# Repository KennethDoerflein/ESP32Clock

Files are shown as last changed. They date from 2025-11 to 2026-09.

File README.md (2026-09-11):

# ESP32-S3 WiFi Clock

This repository contains the firmware for a feature-rich, Wi-Fi connected smart clock powered by an ESP32-S3 microcontroller. It features a large 4" color IPS display, a web-based interface for easy configuration, automatic time synchronization, environmental sensing, and detailed weather forecasts.

## Table of Contents

- [Features](#features)
- [Hardware Requirements](#hardware-requirements)
- [Assembly](#assembly)
- [Wiring](#wiring)
- [Software Setup](#software-setup)
- [Software Architecture](#software-architecture)
- [Usage Guide](#usage-guide)
  - [First-Time Setup](#first-time-setup)
  - [Web Interface](#web-interface)
  - [Physical Button Functions](#physical-button-functions)
  - [Safe Mode & Boot Loop Protection](#safe-mode--boot-loop-protection)
  - [Factory Reset](#factory-reset)
- [Features and Settings in Detail](#features-and-settings-in-detail)
  - [WiFi Page](#wifi-page)
  - [Alarms Page](#alarms-page)
  - [Weather Page](#weather-page)
  - [Settings Page](#settings-page)
  - [Logs Page](#logs-page)
  - [System Page](#system-page)
  - [Temperature & Environmental Sensor Architecture](#temperature--environmental-sensor-architecture)
- [Project Roadmap](#project-roadmap)

## Features

- **Large Color Display**: A 4" 480x320 color IPS display provides a clear and vibrant user interface with smooth anti-aliased font rendering and sprite-based double buffering.
- **Rich Weather Forecasts**: Local weather powered by the Open-Meteo API, including current temperature, apparent "feels like" temperature, relative humidity, wind speed, wind direction, wind gusts, rain probability, cloud cover, UV index, atmospheric pressure, visibility, weather conditions, and daily sunrise/sunset times.
- **Asynchronous Geocoding**: Enter any city or address (e.g., "New York, NY" or "Paris, France") and coordinates are automatically resolved asynchronously via the Open-Meteo Geocoding API with state-code awareness.
- **Multi-Layer Timekeeping & Synchronization**:
  - Hardware DS3231 Real-Time Clock with battery backup ensures uninterrupted timekeeping across power outages.
  - Multi-tier NTP synchronization (primary: `time.nist.gov`, backup: `time.cloudflare.com`, fallback: `us.pool.ntp.org`) with exponential backoff and jitter.
  - Daily automatic synchronization, periodic drift detection and resyncing.
  - Initial boot seeding from RTC to guarantee accurate timestamps prior to network connection.
  - Browser-to-device one-click manual time sync via web interface for air-gapped or offline setups.
  - Automatic Daylight Saving Time (DST) detection and full POSIX timezone support.
- **Advanced Dynamic Alarms**:
  - Configure up to 20 alarms via the web interface.
  - Set custom hour and minute, individual days of the week, or one-time alarms.
  - **Biweekly Scheduling**: Configure alarms to repeat every other week (even or odd week cycles).
  - **3-Stage Progressive Ramping Buzzer**: Transitions from slow beeping (10s) to rapid beeping (20s) to continuous tone.
  - Visual alarm indicators: flashing display backlight and on-screen active alarm / snooze countdown overlay.
  - **Reboot Persistence & Auto-Shutoff**: Automatically resumes ringing if a power cycle occurs while active, and automatically silences after 30 minutes.
  - **Missed Alarm Catch-Up**: Detects and triggers alarms that were missed during unexpected power outages or clock adjustments (capped at 90 minutes).
  - Customizable snooze duration and hold-to-dismiss timer.
- **Environmental Sensing & Thermal Compensation**:
  - BME280 sensor reads ambient room temperature, relative humidity, and pressure with fallback to DS3231 internal sensor.
  - Exponential moving average (EMA) noise filtering.
  - Cold-boot automatic temperature calibration.
  - Configurable enclosure heat compensation factor and manual offset correction.
  - Relative humidity compensation based on the August-Roche-Magnus approximation.
- **Multi-Page Display Management**:
  - 4 built-in display pages: **Clock**, **Weather**, **Weather+Clock** (combined), and **Info**.
  - Enable, disable, and custom-order pages via Move Up / Move Down buttons in the web interface.
  - Configurable startup/default page.
  - Physical button single-press page cycling with display preemption on Core 1 for stutter-free rendering.
- **Customizable Appearance**:
  - Full hex color picker support for individual UI elements: Background, Time, AM/PM, Seconds, Day of Week, Date, Temperature, Humidity, Alarm/Snooze icons, Weather Temp, and Forecast conditions.
  - Screen flip (180° rotation) and color inversion toggles.
  - 12-hour (with AM/PM) or 24-hour format; Fahrenheit or Celsius temperature units.
- **Smart Backlight Control**:
  - Scheduled Auto Brightness with custom day/night transition hours and brightness levels.
  - Manual brightness slider (0–255 PWM).
- **Offline Mode**: Complete disconnected operation with WiFi and online polling turned off.
- **WiFi Connectivity & Captive Portal**:
  - Connects to 2.4 GHz 802.11 b/g/n networks.
  - Automatic Access Point (`Clock-Setup`) and Captive Portal with OS connectivity detection if unconfigured or connection fails.
  - In-browser network scanning and non-blocking credential testing.
  - Custom hostname and mDNS address (e.g., `http://ESP32Clock-XXXXXX.local`).
- **Secure OTA Updates**:
  - Over-the-Air firmware updates directly from the web interface.
  - GitHub Releases integration: one-click check and update directly from GitHub repository releases. This method uses Ed25519 signature verification to prevent unauthorized firmware installations.
  - Manual web uploads are unverified and intended for sideloading/development.
  - Dual-OTA partition layout (`app0` / `app1`) with automatic rollback on boot failure.
- **Diagnostics, Crash Recovery & Safe Mode**:
  - Boot loop detection: enters a minimal recovery environment (`Clock-SafeMode`) after repeated crash-boots.
  - Hardware Task Watchdog Timer (TWDT) monitoring critical FreeRTOS tasks.
  - RTC-backed crash log capturing panic and exception traces across unexpected reboots.
  - Core dump support stored in a dedicated flash partition (`coredump.bin`) with web download and erase tools.
  - Real-time WebSocket live logging and persistent rotating log files (`system.log`).
- **Hardware & Web Factory Reset**: Multiple reset mechanisms (Web UI, runtime BOOT button 10s hold, or power-on Snooze button hold) with options to keep or clear WiFi credentials. LittleFS is formatted during factory reset, wiping system logs so the device is like brand new.

## Hardware Requirements

| Component | Description |
| --- | --- |
| **Microcontroller** | **ESP32-S3-WROOM-1 N16R8** Development Board (16MB Flash, 8MB PSRAM) |
| **Display** | **4" ILI9488 IPS LCD** Display Module (480x320) with SPI interface |
| **Real-Time Clock** | **DS3231** RTC Module with a LIR2032 battery for backup |
| **Sensor** | **BME280** Temperature, Humidity, and Pressure Sensor Module (I2C) |
| **Power Supply** | A reliable 5V USB-C power supply |

## Case 3D Model

[Download](./case%20model/ESP32%20Clock%20Case%204%20inch%20v18.step)

## Parts List

Here is a list of all the components required to build the ESP32-S3 WiFi Clock, along with purchase links:

| Component | Description | Link |
| --- | --- | --- |
| **ESP32-S3-WROOM-1 Development Board** | 16MB Flash, 8MB PSRAM | [AliExpress Link](https://a.aliexpress.com/_mMm2jWD) |
| **4" ILI9488 IPS LCD Display** | 480×320 SPI interface | [AliExpress Link](https://a.aliexpress.com/_mt2vtEh) |
| **DS3231 RTC Module** | With LIR2032 battery backup | [AliExpress Link](https://a.aliexpress.com/_mPeDmLR) |
| **BME280 Sensor Module** | Temperature, Humidity, Pressure, I2C | [AliExpress Link](https://a.aliexpress.com/_mtACD9f) |
| **Active Buzzer** | Any small 5V buzzer | [AliExpress Link](https://a.aliexpress.com/_mKjibtR) |
| **6x6x7.2mm Micro Switch** | For Snooze/Stop functionality | can source locally |
| **USB-C Inlet** | For powering the clock | [AliExpress Link](https://a.aliexpress.com/_msBRQoD) |
| **5V USB-C Power Supply** | Reliable 5V power source | can source locally |
| **Male Machine Pin Headers** | For connecting modules to boards | [AliExpress Link](https://a.aliexpress.com/_mPmIdmp) |
| **DuPont Wires (Male-to-Male / Female-to-Male / Female-to-Female)** | For connections between headers | [AliExpress Link](https://a.aliexpress.com/_mLxGsFP) |
| **DuPont Wire Kit (Headers + Housing)** | 310 pcs set for custom connections | [AliExpress Link](https://a.aliexpress.com/_msXyJap) |
| **Prototype Boards / Perfboards** | For mounting modules | can source locally |
| **Heat-Set Inserts** | For case assembly | can source locally |
| **Screws (M2)** | For case and module mounting | [AliExpress Link](https://a.aliexpress.com/_mtl7Jwt) |

## Assembly

Follow these steps to assemble the ESP32-S3 WiFi Clock:

1. **Flash Firmware**  
   Flash the initial firmware to the ESP32-S3 before starting physical assembly.

2. **Prepare Headers**

   - Replace the existing headers on the display and RTC modules with male machine pin headers.
   - Solder a male dupont header onto the BME280 sensor.

3. **Connect Display**

   - Solder the display header to the prototype board.
   - Route the wires carefully to the opposite side for easy access.  
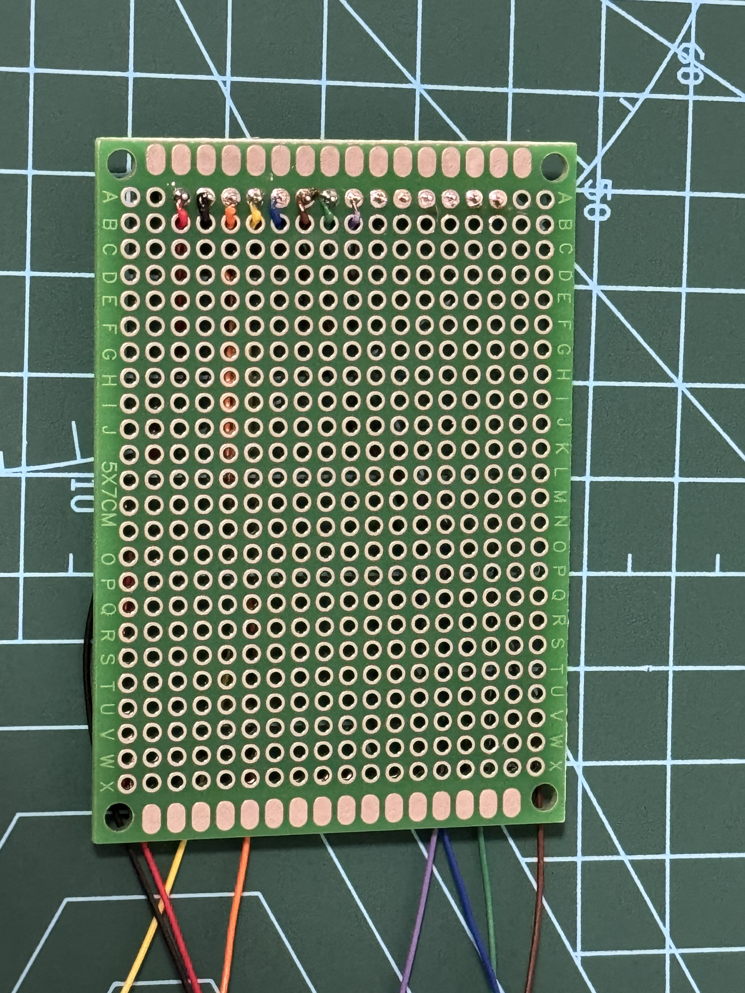
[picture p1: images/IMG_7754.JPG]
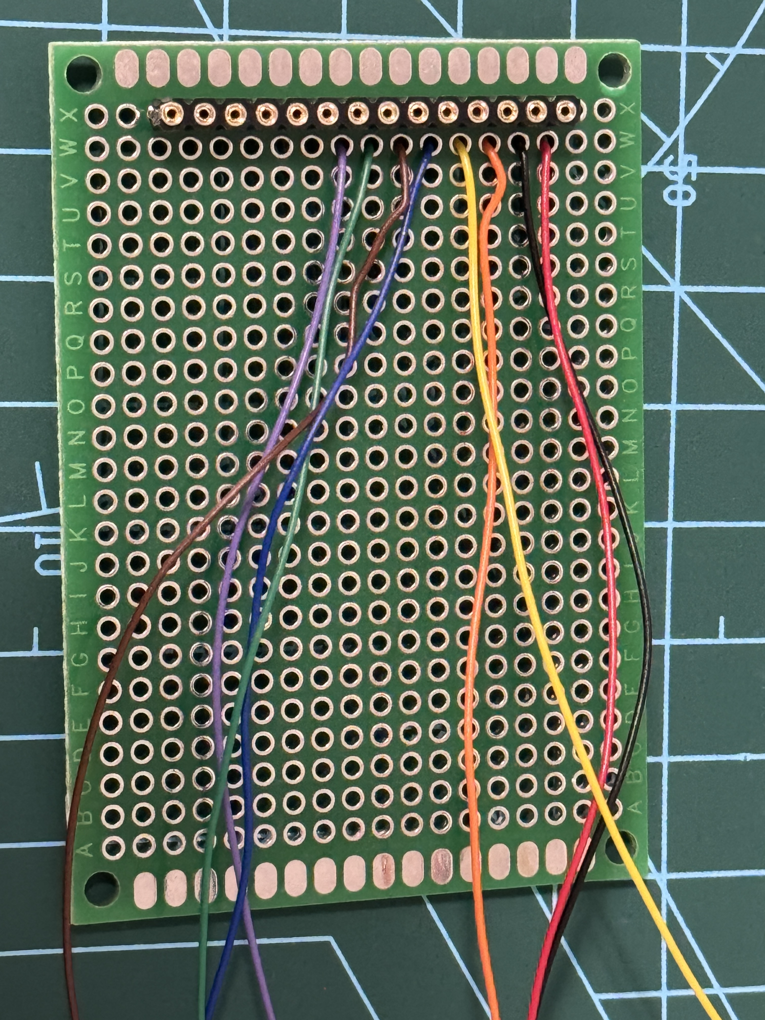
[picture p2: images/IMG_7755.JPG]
      

4. **Solder Remaining Headers**

   - Connect all other headers and wires.
   - Keep wires slightly longer in case adjustments are needed.  
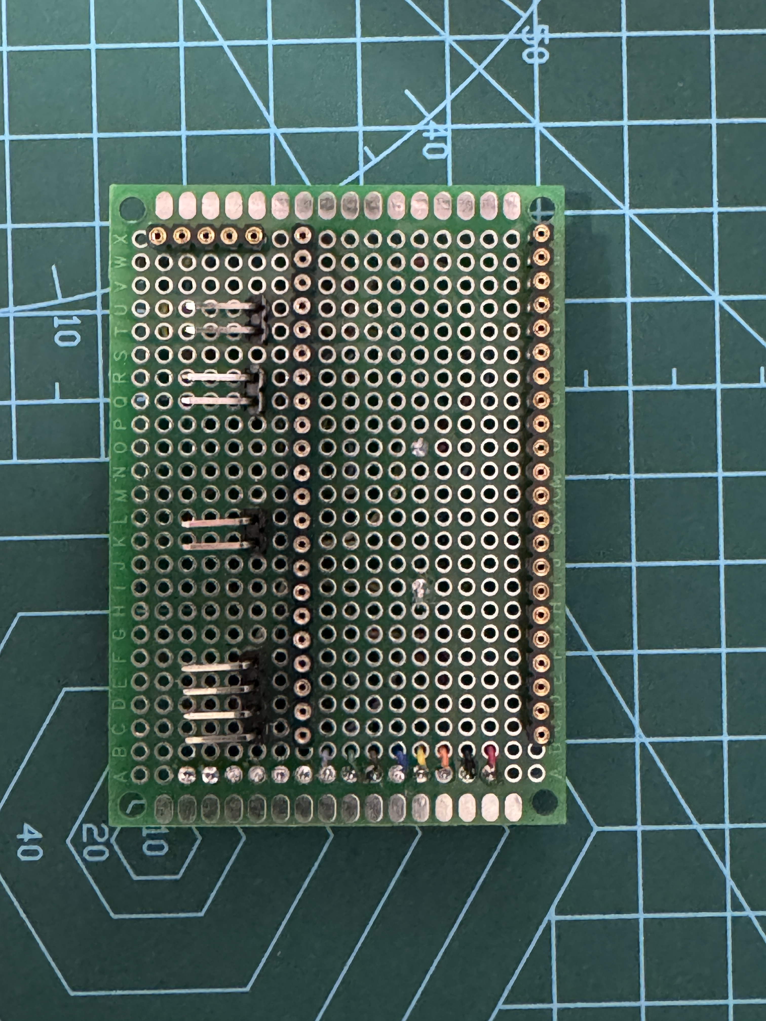
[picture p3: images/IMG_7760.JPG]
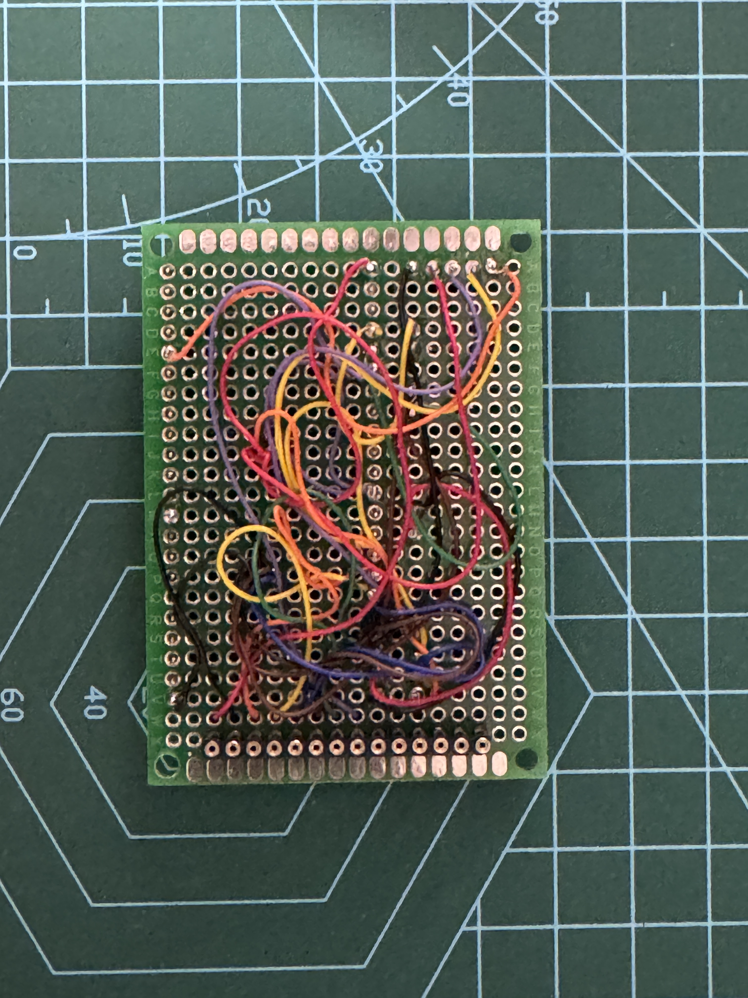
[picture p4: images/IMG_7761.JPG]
      

5. **Fit Components**

   - Ensure the modules fit inside the case.
   - Sand the sides of the RTC if space is tight.  
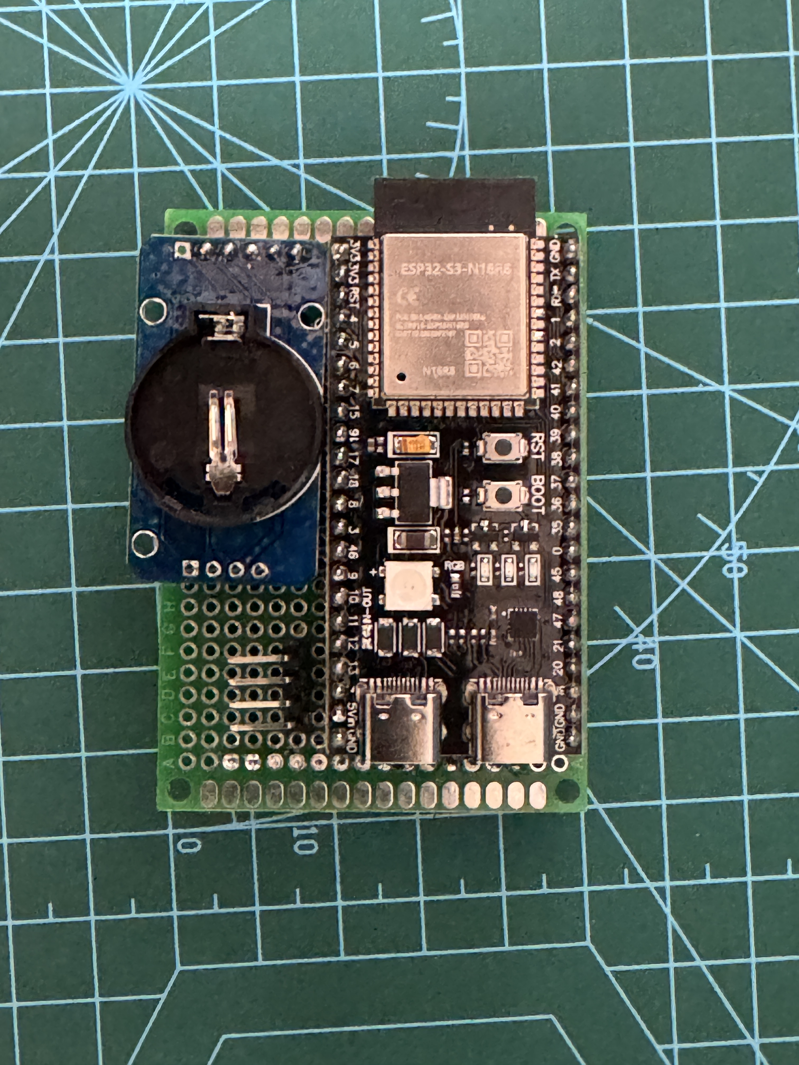
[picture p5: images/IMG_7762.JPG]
     

6. **Install Heat-Set Inserts**

   - Insert into the back panel of the case for M2 screws (sizes: 3×3.2mm and 2×4mm).  
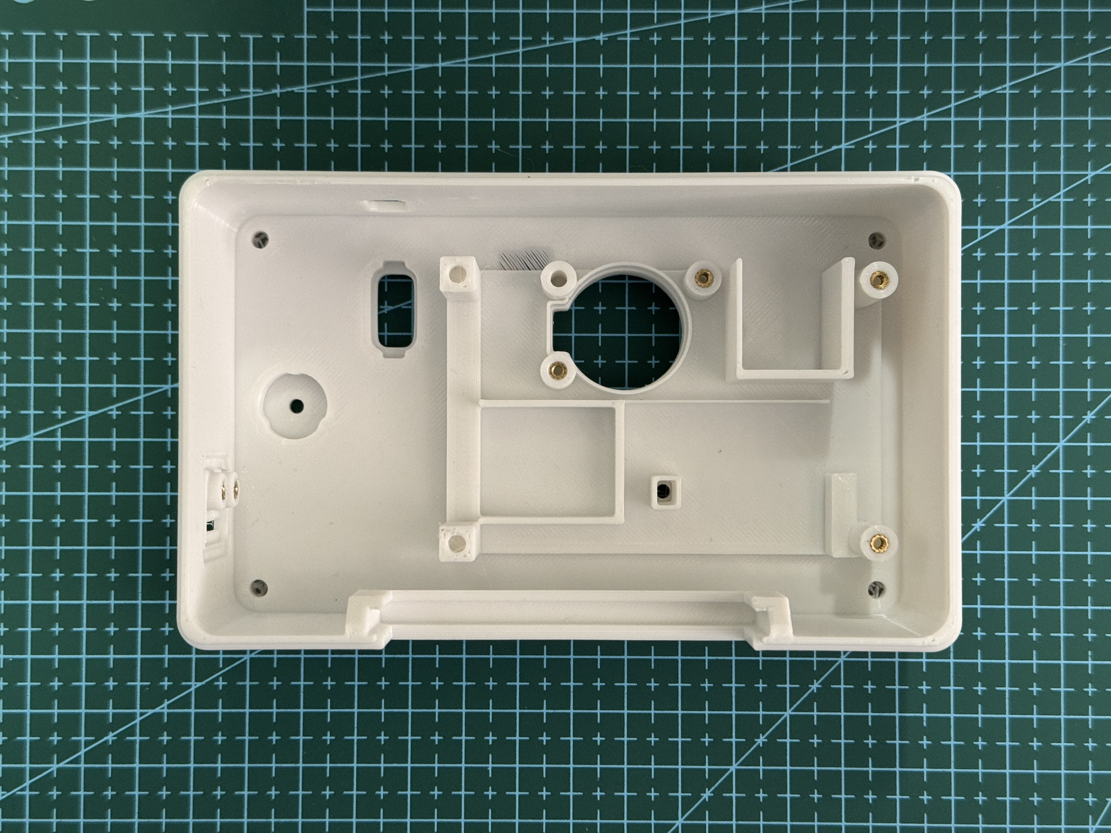
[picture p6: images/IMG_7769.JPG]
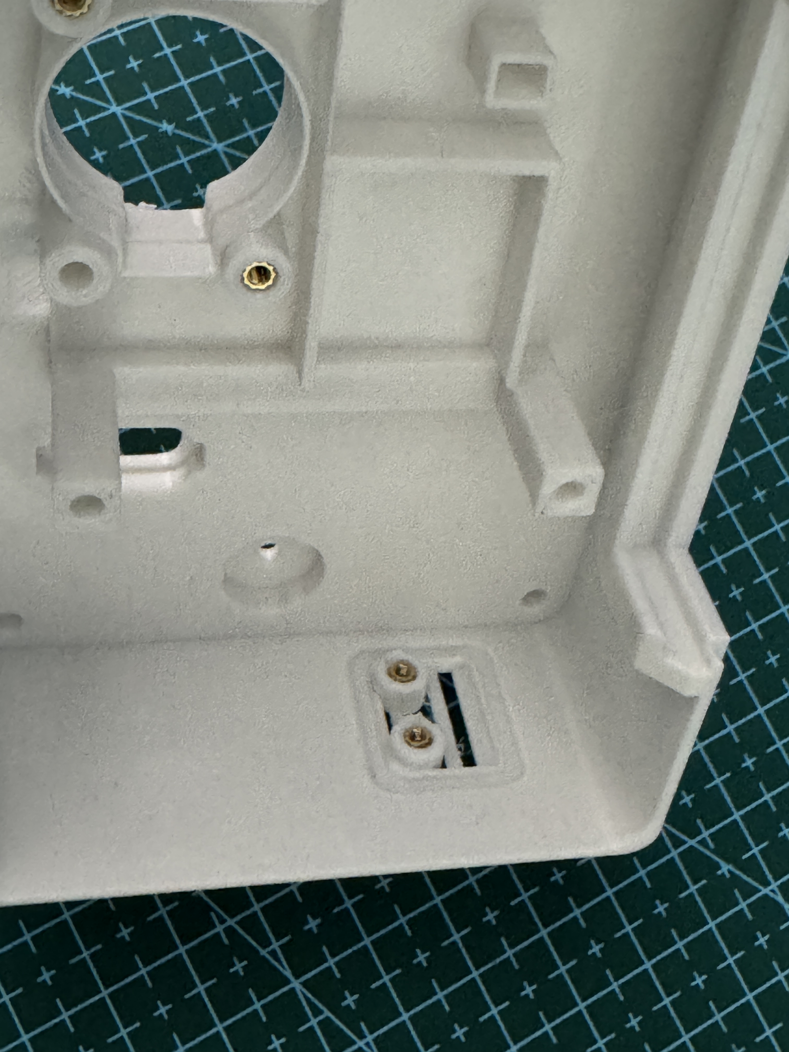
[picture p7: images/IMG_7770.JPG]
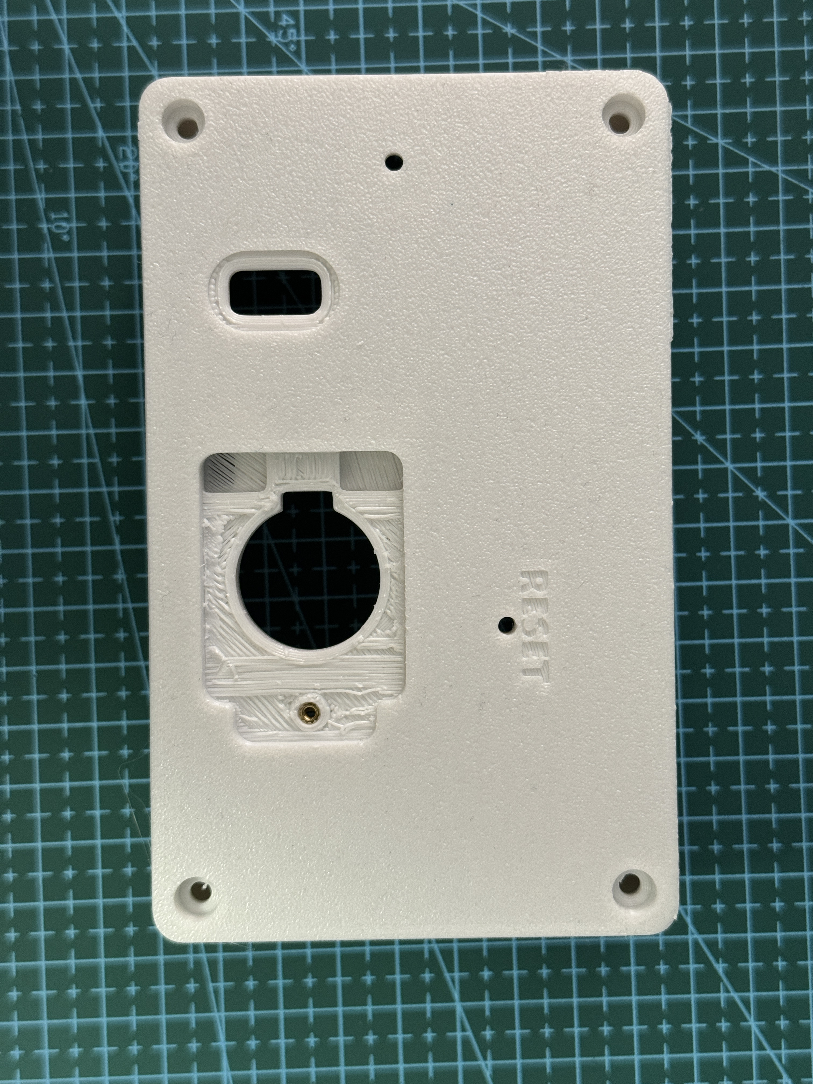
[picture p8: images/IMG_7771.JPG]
       

7. **Install Front Panel Inserts**

   - Install inserts for the display (M2) and posts (M3).

8. **Assemble Components**

   - Plug in all connectors.
   - Secure the display, RTC, and sensors with the appropriate screws.  
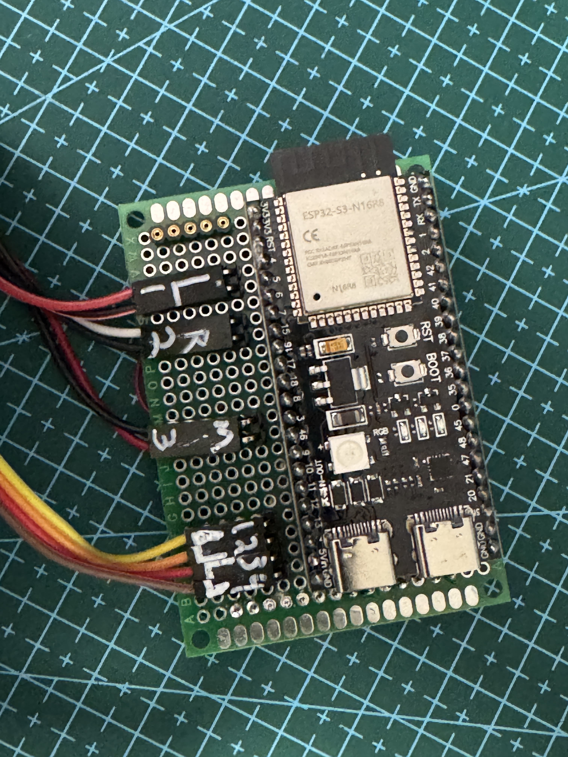
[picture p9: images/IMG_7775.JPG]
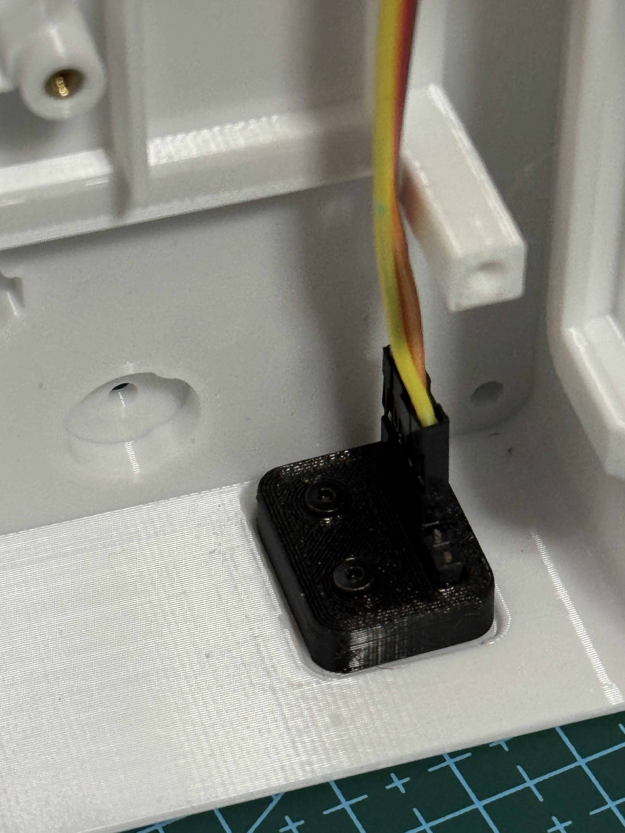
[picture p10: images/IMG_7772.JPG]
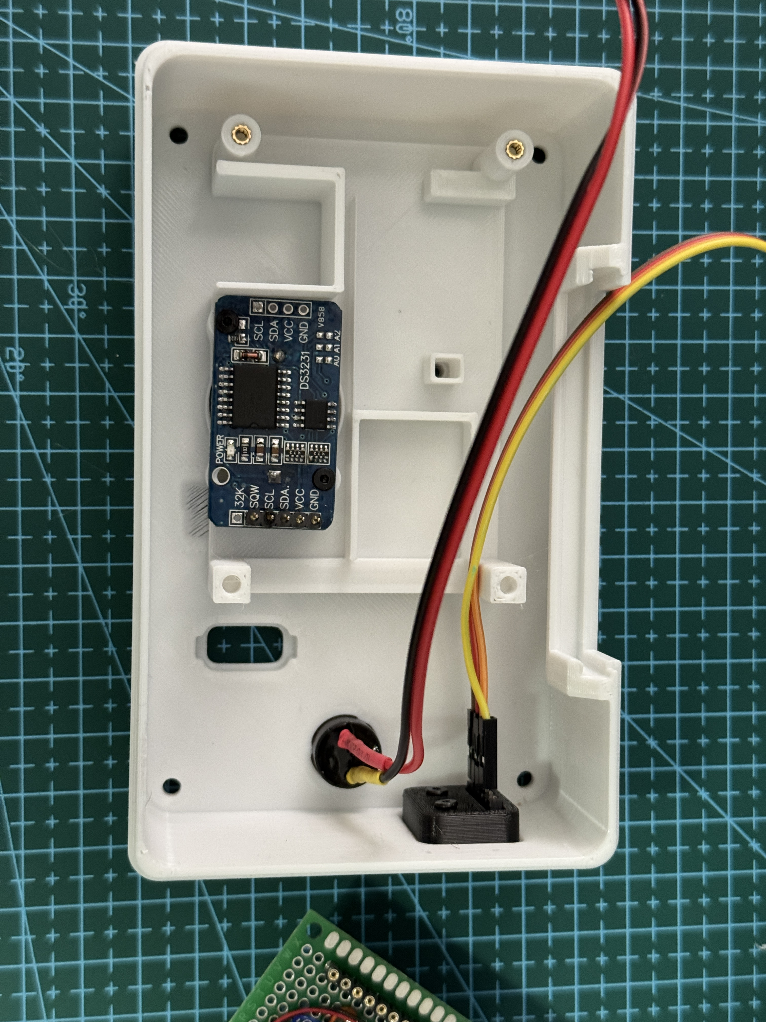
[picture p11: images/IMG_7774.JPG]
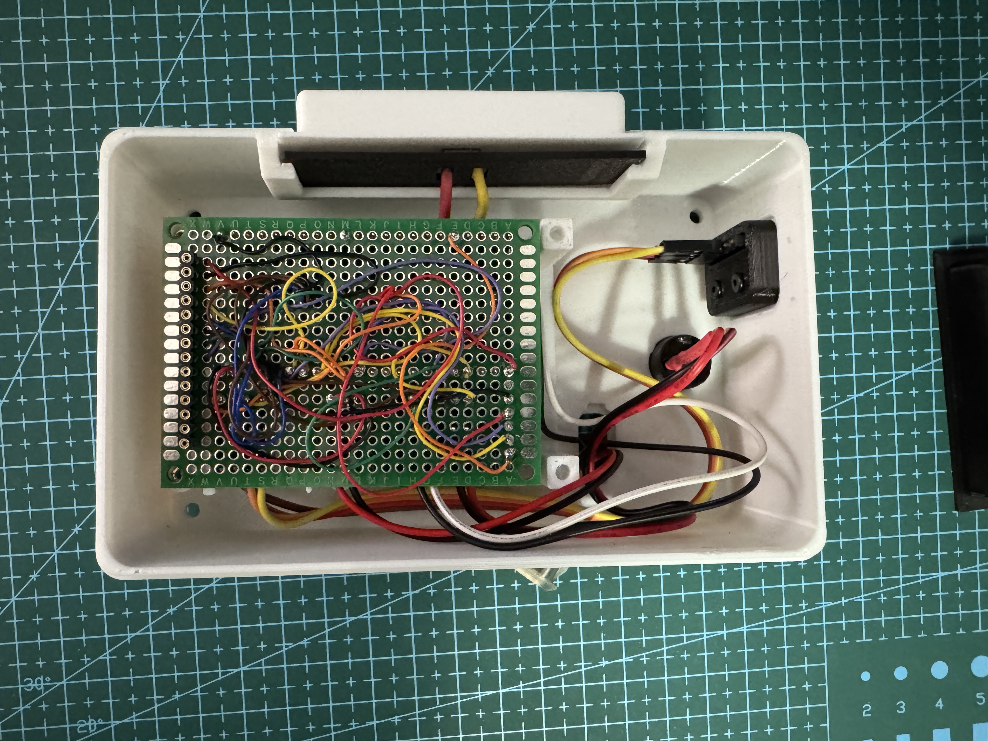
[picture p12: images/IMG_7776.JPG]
        

9. **Close Case and Power On**
   - Screw the case together and connect power.  
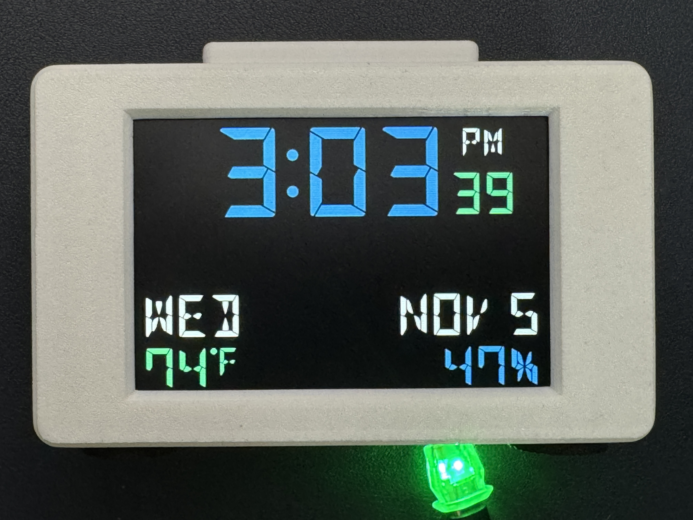
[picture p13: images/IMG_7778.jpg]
     

## Wiring

The components are connected using the I2C and SPI buses.

| Component | Pin | ESP32-S3 GPIO | Notes |
| --- | --- | --- | --- |
| **4" ILI9488 IPS (SPI)**  | VCC | 3.3V | Connect to 3.3V pin |
| | GND | GND | Common ground |
| | CS | GPIO 10 | Chip Select |
| | RST | GPIO 11 | Reset |
| | DC | GPIO 12 | Data/Command |
| | MOSI | GPIO 13 | Data In |
| | SCK | GPIO 14 | Clock |
| | LED | GPIO 6 | Backlight (PWM) |
| | MISO | UNUSED | Data Out |
| **DS3231 & BME280 (I2C)** | VCC | 3.3V | Shared 3.3V |
| | GND | GND | Shared ground |
| | SDA | GPIO 8 | Shared data line |
| | SCL | GPIO 9 | Shared clock line |
| DS3231 | SQW | GPIO 2 | Interrupt for alarms  |
| **Active Buzzer** | + | GPIO 4 | Any free GPIO |
| | - | GND | Common ground |
| **Stop/Snooze Button** | One leg | GPIO 5 | Use INPUT_PULLUP mode |
| | Other leg | GND | Common ground |

## Software Setup

This project is developed using **PlatformIO**.

### Libraries

The following libraries are required and are automatically managed by PlatformIO via the `platformio.ini` file:

- `bodmer/TFT_eSPI`
- `bblanchon/ArduinoJson`
- `adafruit/RTClib`
- `adafruit/Adafruit BME280 Library`
- `esphome/ESPAsyncWebServer-esphome`
- `esphome/AsyncTCP-esphom`

### Build Instructions

1.  **Clone the Repository**:
    ```bash
    git clone https://github.com/KennethDoerflein/ESP32Clock.git
    cd ESP32Clock
    ```
2.  **Open in PlatformIO**: Open the project folder in VS Code with the PlatformIO extension installed.
3.  **Build & Upload**: Use the PlatformIO "Build" and "Upload" commands to compile and flash the firmware to your ESP32-S3.

---

## Software Architecture

The firmware is organized into a collection of singleton manager classes and modular components running across the ESP32-S3's dual cores (Core 0 for network/logic/logging; Core 1 for display rendering and timekeeping):

- **`AlarmManager`**: Manages physical alarm ringing, buzzer frequency ramping across 3 progressive stages (slow beep -> fast beep -> continuous), display backlight flashing, reboot resume, and auto-shutoff timer.
- **`ButtonManager`**: Provides debounced interrupt-based input handling for the multi-function physical button (press durations, page switching, snooze, and hold-to-dismiss).
- **`ClockWebServer`**: Asynchronous web server hosting the configuration UI, REST API endpoints, live log WebSocket server, captive portal, and firmware upload receiver.
- **`ConfigManager`**: Thread-safe configuration manager utilizing ESP32 NVS Preferences for persistent storage with write debouncing to protect flash memory.
- **`DisplayManager`**: Orchestrates active display page lifecycle, page transitions, alarm overlay banners, dismiss progress bars, and status icons with display preemption on Core 1 for zero jitter.
- **`Display`**: Low-level TFT display abstraction (ILI9488 SPI driver), screen rotation, color inversion, and LEDC PWM backlight control.
- **`FirmwareVerifier`**: Provides cryptographic verification using Ed25519 signatures and SHA-256 streaming hashing before applying firmware updates.
- **`NtpSync`**: Multi-tiered NTP client featuring exponential backoff, jitter, and automatic fallback across NIST, Cloudflare, and NTP Pool servers.
- **`SensorModule`**: Interfaces with the BME280 (I2C) and DS3231 sensors, implementing I2C bus recovery, exponential moving average (EMA) noise filtering, enclosure thermal compensation, and August-Roche-Magnus humidity correction.
- **`SerialLog`**: Centralized thread-safe logger mirroring serial output to a live WebSocket feed, persistent rotating LittleFS file (`system.log`), and RTC memory crash dump buffer.
- **`TimeManager`**: High-accuracy timekeeping coordinator bridging the DS3231 hardware RTC and ESP32 system clock, tracking Daylight Saving Time, drift compensation, missed alarm detection, and biweekly parity calculations.
- **`UpdateManager`**: Handles OTA firmware updates via file upload and automated GitHub Releases checks with cryptographic signature verification and dual-OTA partition rollback safety.
- **`WeatherService`**: Handles asynchronous geocoding and fetches comprehensive weather metrics from Open-Meteo via HTTPS with PSRAM-backed JSON filtering; network loops execute in the background Logic Task (Core 0) with HTTPS requests offloaded to a persistent FreeRTOS worker (`WeatherUpdate` on Core 1 at priority 1, preempted by Core 1 display rendering).
- **`WiFiManager`**: Manages WiFi STA connection, automatic reconnection, non-blocking connection tests, DNS captive portal, network scanning, and mDNS responder.
- **`Page`**: An abstract base class for display pages:
  - **`ClockPage`**: Large retro-styled digital clock face with time, AM/PM, seconds, day of week, date, indoor temperature, indoor humidity, and next alarm indicators.
  - **`WeatherPage`**: Dedicated weather display showing current outdoor temperature, condition description, humidity, wind, and rain chance.
  - **`WeatherClockPage`**: Split-layout screen combining clock display with live outdoor conditions and indoor environmental data.
  - **`InfoPage`**: Static information screen showing device hostname, IP address, and firmware version.

---

## Usage Guide

### First-Time Setup

1.  On the first boot, or if WiFi credentials are not configured/valid, the clock will start a Wi-Fi Access Point (AP). The SSID will be **`Clock-Setup`**.
2.  Connect to this network from your phone or computer.
3.  Open a web browser and navigate to the clock's static IP address, which is **`http://192.168.4.1`**. This address is fixed when the clock is in AP mode.

### Web Interface

The web interface provides access to all the clock's settings. Once connected to your WiFi network, you can access the web interface by navigating to the IP address shown on the clock's display or by using its mDNS address (e.g., `http://ESP32Clock-XXXXXX.local`).

The web interface is organized into several sections:

- **Configure WiFi**: For connecting to your local network and setting a hostname.
- **Alarms**: For setting and managing up to 20 alarms.
- **Weather**: For configuring the location and viewing weather status.
- **Settings**: For adjusting display, time, brightness, and page configuration.
- **Logs**: For viewing live logs and managing log files.
- **System**: For system-level actions like updates, reboots, and viewing system information.

### Physical Button Functions

The physical button (connected to GPIO 5) is debounced via interrupts and serves multiple functions depending on the system state:

- **Normal Operation (Idle)**:
  - A **short press** cycles through the configured enabled display pages in sequence (e.g., Clock -> Weather -> Info -> Weather+Clock).
- **Alarm Ringing**:
  - A **short press** will **snooze** the ringing alarm for the configured snooze duration (default 9 minutes).
  - **Pressing and holding** the button will **dismiss** the alarm. A graphical progress bar fills at the bottom of the screen while held; once the configured dismiss duration (default 3 seconds) is reached, the alarm is dismissed.
- **Alarm Snoozed**:
  - **Pressing and holding** the button for the dismiss duration will cancel snooze for all snoozed alarms, with real-time visual progress feedback on the display.

### Safe Mode & Boot Loop Protection

The firmware includes multi-stage boot protection to prevent bricking if an error or crash occurs during startup:

- **Boot Counter**: A persistent counter in NVS is incremented immediately upon boot. It is only reset to zero after 30 seconds of stable, uninterrupted uptime.
- **Automatic Firmware Rollback**: If repeated crashes occur and a previous working firmware partition is available in dual-OTA layout (`app0` / `app1`), the device automatically rolls back to the prior firmware version.
- **Safe Mode Environment**: If 10 consecutive crash-boots occur without rollback, the clock halts normal initialization and enters **Safe Mode**:
  - Starts minimal recovery peripherals only (screen, WiFi, and a lightweight web recovery server).
  - Attempts to connect to saved WiFi or launches fallback AP **`Clock-SafeMode`** (`http://192.168.4.1`).
  - Displays recovery instructions and IP on the screen.
  - Allows uploading a fixed firmware binary via browser to recover the device without physical disassembly or serial flashing.

### Factory Reset

There are three ways to perform a factory reset:

1.  **Via the Web Interface**: Navigate to the "System" page and click either:
    - **Factory Reset**: Erases all stored settings (including WiFi credentials, alarms, and display preferences), formats LittleFS, and reboots the device into setup mode.
    - **Factory Reset (Keep WiFi)**: Erases all alarms, colors, and display settings, formats LittleFS, but preserves saved WiFi credentials.
2.  **Boot-Time Reset (Physical)**:
    - Disconnect the clock from power.
    - Press and hold the **Snooze button** (GPIO 5).
    - Reconnect power while continuing to hold the button.
    - Hold for **10 seconds**. The screen will display `"Hold for factory reset"` and then trigger the reset.
3.  **Runtime Reset (Physical)**:
    - While the clock is running normally, press and hold the **Boot button** (GPIO 0) on the ESP32 board for **10 seconds**.

---

## Features and Settings in Detail

### WiFi Page

This page allows you to connect the clock to your local WiFi network.

- **Scan for Networks**: Click the "Scan" button to see a list of available 2.4 GHz WiFi networks with signal strength. Clicking on a network name automatically populates the SSID field.
- **SSID & Password**: Manually enter or adjust your network's credentials.
- **Test Connection**: Test credentials non-blockingly without saving or rebooting to confirm valid authentication.
- **Save & Reboot**: Save credentials to persistent NVS storage and automatically reboot into station mode.
- **Hostname**: Set a custom network hostname (1–63 alphanumeric characters or hyphens). This configures the DHCP client name and the mDNS local domain (e.g., `http://your-hostname.local`).

### Alarms Page

- **Dynamic Alarms**: Add and configure up to 20 alarms simultaneously. Click "Add Alarm" to create a new one.
- **Alarm Configuration**:
  - **Enable/Disable**: Toggle any alarm on or off individually.
  - **Time**: Select hour and minute in 12-hour or 24-hour format.
  - **Repeat Days**: Choose specific days of the week (Sunday through Saturday), or leave days unselected for a one-time alarm that auto-disables after ringing.
  - **Biweekly Mode**: Enable alternating two-week alarm schedules (even vs. odd ISO week parity cycles), ideal for shift work or rotating schedules.
  - **Delete**: Permanently remove alarms.
- **Progressive Ramping Buzzer**:
  - **Stage 1 (0–10s)**: Gentle slow beeps (200ms on, 800ms off).
  - **Stage 2 (10–30s)**: Urgent fast beeps (150ms on, 150ms off).
  - **Stage 3 (30s–30m)**: Continuous high tone.
  - **Auto-Shutoff**: Silences automatically after 30 minutes to prevent unattended ringing.
- **Visual Feedback**:
  - Flashing screen backlight while ringing.
  - Large on-screen ringing banner displaying "ALARM" (or remaining countdown MM:SS when snoozed).
  - When snoozed, an icon and countdown show the remaining snooze time.
  - Animated dismiss progress bar at the bottom of the screen during button holds.
- **Snooze & Dismiss Controls**:
  - **Snooze Duration**: Configurable snooze time in minutes (default 9 minutes).
  - **Dismiss Hold Duration**: Configurable hold time in seconds required to dismiss an active alarm or cancel snooze (default 3 seconds).
- **Power Failure & Clock Jump Resiliency**:
  - **Ringing State Persistence**: If power is cut while an alarm is ringing, the clock detects the active state upon boot, resumes ringing with the appropriate elapsed stage offset, and flashes the display.
  - **Missed Alarm Window Catch-Up**: Checks for alarms that should have fired during unexpected power outages, reboots, or manual/NTP clock jumps and triggers them immediately (capped at 90 minutes).

### Weather Page

This page allows you to configure location and inspect comprehensive weather metrics.

- **Location Input**: Enter a city or address (e.g., "Seattle, WA", "Berlin, Germany", or zip code) and click "Save Location".
- **Asynchronous Geocoding**: Resolves addresses in the background without blocking web requests or clock rendering, supporting international locations and US state abbreviations.
- **Automatic Coordinates**: Stores resolved latitude and longitude in NVS; clearing the field disables weather polling.
- **Comprehensive Live Metrics**:
  - Current Temperature and Apparent ("Feels Like") Temperature.
  - Relative Humidity (%) and Precipitation Chance (%).
  - Wind Speed, Wind Direction (compass bearing, e.g., "NW"), and Wind Gusts.
  - Atmospheric Pressure (hPa) and Visibility (meters).
  - Cloud Cover (%) and UV Index.
  - WMO Condition Description (e.g., "Clear", "Partly Cloudy", "Rain Showers", "Thunderstorm").
  - Sunrise and Sunset times (formatted according to 12h/24h preference).
- **Force Sync**: Trigger an immediate weather data refresh on demand.
- **Background FreeRTOS Worker**: Dedicated persistent task on Core 1 with 10-minute update interval, exponential failure backoff, and PSRAM JSON parsing to avoid heap fragmentation.

### Settings Page

Divided into "General" and "Display" tabs.

#### General Tab

- **Page Configuration**:
  - **Default Page**: Choose which page the clock defaults to on startup (Clock, Weather, Info, or Weather+Clock).
  - **Enabled Pages**: Reorder pages via Move Up / Move Down buttons or uncheck to remove them from physical button cycling.
- **Offline Mode**: Completely turns off WiFi and all network operations (NTP, weather). Timekeeping and sensor monitoring continue uninterrupted.
- **Brightness Settings**:
  - **Auto Brightness**: Schedule-based backlight dimming. Configure daytime start hour, night start hour, daytime brightness level (0–255), and night brightness level (0–255).
  - **Manual Brightness**: Fixed brightness slider active when Auto Brightness is disabled.
- **Time and Display Format**:
  - **24-Hour Format**: Toggle between 12-hour (with AM/PM) and 24-hour formats.
  - **Temperature Units**: Toggle globally between Celsius (°C) and Fahrenheit (°F).
  - **Flip Display Orientation**: Rotates the display 180 degrees.
  - **Invert Colors**: Hardware IPS color inversion toggle.
- **Timezone**: Select from standard POSIX timezone definitions with automated Daylight Saving Time transitions.
- **Temperature Sensors & Calibration**:
  - **Auto Temperature Calibration**: Performs automatic cold-boot calibration of the ambient sensor.
  - **Manual Temperature Correction**: Set a fixed temperature offset (±°C) to adjust readings.
  - **Temperature Compensation Factor**: Adjusts the ratio (0.00 to 1.00) of internal RTC temperature used to dynamically subtract enclosure heat from the ambient sensor.
  - **August-Roche-Magnus Humidity Correction**: Automatically recalculates accurate relative humidity from the dew point whenever temperature offsets are applied.
- **Reset General Settings**: Reverts general configuration options to factory defaults.

#### Display Tab

Customizes the color palette of every element rendered on the screen:

- **Color Pickers**: 10 distinct hex color pickers in the web UI for Background, Time, AM/PM Indicator (TOD), Seconds, Day of Week, Date, Indoor Temperature, Indoor Humidity, Weather Temperature, and Forecast Condition text (with system defaults for alarm and snooze icons).
- **Reset to Defaults**: Restores all display colors to their default retro-cyan/green palette.

### Logs Page

Diagnostic tools for live monitoring and crash analysis:

- **Live Log Viewer**: Real-time streaming console output delivered via WebSockets with automatic reconnection and client cleanup.
- **System Log File (`system.log`)**:
  - Persistent log stored in LittleFS with automatic rotation at 256 KB (`system.log.old`).
  - Web download button and manual "Rotate Log" trigger.
  - Thread-safe write buffering to prevent filesystem corruption.
- **Crash Log File (`crash.log`)**:
  - Diagnostic crash log recording boot reset reasons, panic backtraces, and pre-crash log buffer contents captured in non-volatile RTC memory across watchdog resets and brownouts.
  - Download and clear crash log endpoints.
- **ESP32 Core Dump (`coredump.bin`)**:
  - Downloads raw ELF/binary core dumps saved to the dedicated `coredump` partition (`0xE10000`) for post-mortem GDB debugging.
  - Web button to clear/erase core dump flash partition.

### System Page

System diagnostics, updates, and maintenance:

- **Cryptographic Firmware Update**:
  - **Manual Upload**: Upload a compiled `firmware.bin` directly from your browser.
  - **GitHub Update**: Queries GitHub Releases API for the latest release tag. Downloads `firmware.bin`, `firmware.sig`, and `firmware.sha256`, verifying the Ed25519 cryptographic signature against the onboard public key before flashing.
  - **Dual-OTA Partitions & Rollback**: Uses `app0` / `app1` partitions. If newly flashed firmware fails to run stably for 30 seconds, the device automatically cancels the update and rolls back to the previous operational firmware.
- **System Actions**:
  - **Reboot Device**: Cleanly flushes settings and performs a software restart.
  - **Factory Reset**: Erases all configuration in NVS flash and restarts.
  - **Factory Reset (Keep WiFi)**: Clears alarms, display settings, and preferences while preserving WiFi credentials.
  - **NTP Time Sync**: Manually triggers an immediate NTP synchronization cycle.
  - **Manual Browser Time Sync**: One-click button (`/api/system/time`) that writes the client browser's exact Unix epoch to the DS3231 hardware RTC and system clock, calculating drift diagnostics and catching missed alarms.
- **Live System Statistics**:
  - **Free Heap**: Real-time available heap memory and minimum lifetime heap.
  - **Uptime**: Continuous device run time since last boot.
  - **WiFi RSSI**: Signal strength in dBm.
  - **ESP32 Core Temperature**: Internal silicon temperature measured by on-chip thermal sensor.
  - **Sensor Status**: Detection indicators and raw readings for BME280, DS3231 RTC, and enclosure compensation offsets.

### Temperature & Environmental Sensor Architecture

1.  **BME280 Environmental Sensor**: Connected via shared I2C bus (GPIO 8/9). Measures ambient temperature, relative humidity, and barometric pressure. Features 9-clock I2C bus recovery on startup, exponential moving average (EMA) noise smoothing, and thermal inertia modeling.
2.  **DS3231 High-Precision RTC**: Battery-backed I2C timekeeper with an internal temperature-compensated crystal oscillator (TCXO). Its internal temperature reading is used as an enclosure reference to subtract circuit heat from the ambient sensor.
3.  **ESP32-S3 Internal Sensor**: Built-in silicon temperature sensor monitored for system health diagnostics and CPU load tracking.
4.  **Brightness-Scaled Thermal Compensation**: Blends internal core and RTC temperatures (`0.25 * core + 0.75 * RTC`) to model enclosure heating, dynamically scaled by backlight PWM duty cycle (`0.80 + 0.20 * brightness_ratio`) and smoothed by an exponential moving average (EMA, alpha=0.02) to track enclosure thermal inertia without sudden jumps.

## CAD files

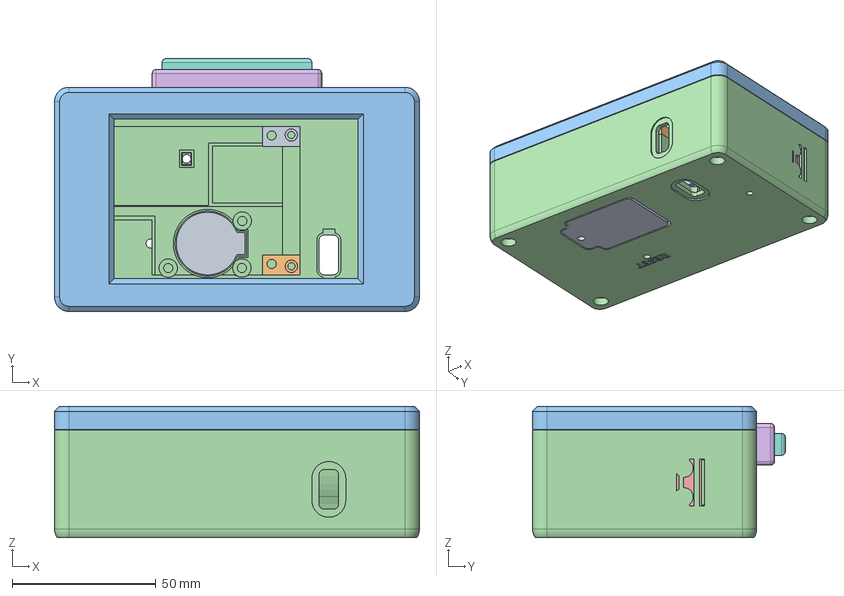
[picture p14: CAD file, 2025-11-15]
case model/ESP32 Clock Case 4 inch v18.step
127.0 x 88.0 x 45.7 mm

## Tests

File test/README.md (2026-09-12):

# ESP32Clock Unit Test Suites

This directory contains the unit tests for the ESP32Clock project.

The test framework uses [Unity](http://www.throwtheswitch.org/unity) via PlatformIO for embedded/C++ testing and Python's standard `unittest` framework for build-time and OTA signing scripts.

## Test Suites Overview

### 1. Embedded C++ Tests (PlatformIO Test Runner / Unity)

| Test Suite | Path | Description |
| :--- | :--- | :--- |
| **test_alarm** | `test/test_alarm/test_alarm.cpp` | Comprehensive coverage of the `Alarm` class: default state, hour/minute clamping, ID & enabled states, snooze mechanics, DST spring forward skipped hours, DST fall back duplicate ring prevention, biweekly parity, and dismiss behavior. |
| **test_config** | `test/test_config/test_config.cpp` | Directly tests `ConfigManager` singleton methods: default constants, enabled pages order, alarm replacement and vector manipulation, alarm summary calculations, first-snoozed search, and persistent settings getters/setters. |
| **test_constants** | `test/test_constants/test_constants.cpp` | Invariant checks for hardware GPIO pinouts, buzzer progressive ramping and beeping cadences, UI sprite geometry bounds, brightness limits, and safe-mode boot thresholds. |
| **test_firmware_verifier** | `test/test_firmware_verifier/test_firmware_verifier.cpp` | Cryptographic verification tests for `FirmwareVerifier`: NIST SHA-256 test vectors (empty input, known strings), streaming hash calculation context, hex string parsing (valid, invalid lengths, invalid characters), and public key format verification. |
| **test_lock_guard** | `test/test_lock_guard/test_lock_guard.cpp` | Multi-core synchronization tests for `LockGuard` and `RecursiveLockGuard`: null pointer safety, RAII acquisition and release, and nested recursive mutex re-entrancy. |
| **test_scripts** | `test/test_scripts/test_scripts.cpp` | C++ test validating build-time version injection: ensures `FIRMWARE_VERSION` is non-empty and follows semantic or development version formatting conventions (`v*` or `dev-*`). |
| **test_sensor** | `test/test_sensor/test_sensor.cpp` | Sensor calculations and temperature conversions: zero-offset preservation, zero-humidity protection against `log(0)` / `NaN`, physical cooling/warming humidity compensation curves, boundary clamping, and bidirectional Celsius/Fahrenheit conversion precision. |
| **test_time_manager** | `test/test_time_manager/test_time_manager.cpp` | Directly exercises `TimeManager` static formatting helpers: 12-hour and 24-hour time formatting, AM/PM calculation, month and day-of-week string conversions, seconds formatting, and `NextAlarmTime` strict weak ordering. |
| **test_utils** | `test/test_utils/test_utils.cpp` | Utility routines: RGB565 color conversions for primary and UI palette colors, hex case insensitivity, boundary conditions, and RFC 1123 hostname validation rules. |
| **test_weather_service** | `test/test_weather_service/test_weather_service.cpp` | Weather parsing and data representations: 16-point wind direction cardinal mapping, 22.5-degree boundaries and angular wrapping, WMO weather code translations, RFC 3986 URL encoding, and whole-word presence matching. |

### 2. Build-Time and OTA Script Tests (Python `unittest`)

| Test File | Path | Description |
| :--- | :--- | :--- |
| **test_ota_scripts** | `test/test_ota_scripts.py` | Exercises build-time and OTA signing helpers: Ed25519 public key C-array generation, header file updates, SHA-256 firmware hash calculations with NIST vectors, firmware artifact path resolution, private key parsing and validation, and development version string formatting. |

## Running Tests

### Running Python Tests (Host Machine)
To run the build and OTA script tests on your local machine:
```bash
python test/test_ota_scripts.py
```
Or via the test runner shim:
```bash
python -m unittest discover -s test
```

### Running Embedded C++ Tests (PlatformIO)
To run the C++ test suites on physical ESP32-S3 hardware connected via USB serial:
```bash
pio test -e esp32s3_n16r8
```
To run a specific test suite:
```bash
pio test -e esp32s3_n16r8 -f test_sensor
```

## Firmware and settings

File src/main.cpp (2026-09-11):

// main.cpp

/**
 * @file main.cpp
 * @brief The main entry point for the ESP32 Clock application.
 *
 * This file contains the primary setup and loop functions that orchestrate
 * the device's operation, including initialization of all modules, handling
 * WiFi connectivity, and managing the main application logic loop.
 */

#include <Arduino.h>
#include <memory> // For std::unique_ptr
#include <ESPmDNS.h>
#include <Preferences.h>

#include "Constants.h"
// Include all custom module headers.
#include "ConfigManager.h"
#include "AlarmManager.h"
#include "SensorModule.h"
#include "Display.h"
#include "TimeManager.h"
#include "WiFiManager.h"
#include "DisplayManager.h"
#include "pages/ClockPage.h"
#include "pages/InfoPage.h"
#include "pages/WeatherPage.h"
#include "pages/WeatherClockPage.h"
#include "ClockWebServer.h"
#include "SerialLog.h"
#include <LittleFS.h>
#include "ButtonManager.h"
#include "WeatherService.h"
#include "NtpSync.h"
#include "UpdateManager.h"
#include "WebContent.h"
#include <ESPAsyncWebServer.h>
#include <DNSServer.h>
#include <esp_task_wdt.h>
#include <esp_ota_ops.h>
#include <Update.h>
#if __has_include("version.h")
// This file exists, so we'll include it.
#include "version.h"
#else
// "version.h" was not found, so we'll include the backup.
#include "version.h.default"
#endif

volatile bool g_alarm_triggered = false;

// --- Global Variables for Timers & Button Handling ---
unsigned long g_lastLoopTime = 0;
unsigned long g_bootButtonPressTime = 0;

// --- Button State for Alarm Handling ---
static unsigned long s_alarmButtonPressTime = 0;
static bool s_actionTaken = false;

enum AlarmState
{
  IDLE,
  RINGING,
  SNOOZED
};
AlarmState g_alarmState = IDLE;

ButtonManager snoozeButton(SNOOZE_BUTTON_PIN);

// --- Task Handles ---
TaskHandle_t g_logicTaskHandle = NULL;

/**
 * @brief Updates the global alarm state based on the current system status.
 *
 * This function centralizes the logic for determining whether the system
 * should be in the IDLE, RINGING, or SNOOZED state. It checks the
 * AlarmManager and the configuration to make the decision.
 */
void updateAlarmState(bool anySnoozed)
{
  auto &alarmManager = AlarmManager::getInstance();
  AlarmState oldState = g_alarmState;

  // Determine the new state based on current conditions.
  // The order of checks is important: ringing takes precedence over snoozed.
  AlarmState newState;
  if (alarmManager.isRinging())
  {
    newState = RINGING;
  }
  else
  {
    newState = anySnoozed ? SNOOZED : IDLE;
  }

  // --- Handle State Transitions ---
  if (newState != oldState)
  {
    g_alarmState = newState; // Update the global state
    SerialLog::getInstance().printf("Alarm state changed from %d to %d\n", oldState, newState);

    // When moving to a state that requires polling, detach the interrupt.
    // When returning to IDLE, re-attach it.
    if (newState == IDLE)
    {
      snoozeButton.clearNewPress(); // Discard button press generated during alarm silencing/snoozing
      snoozeButton.attach();
    }
    else
    {
      snoozeButton.detach();
      snoozeButton.clearNewPress(); // Ensure no stale presses are carried over
    }
  }
}

// --- RTC Alarm ISR ---
void IRAM_ATTR onAlarm()
{
  g_alarm_triggered = true;
}

/**
 * @brief Resets the safe mode boot counter to zero.
 *
 * Called after a successful setup to indicate the firmware booted cleanly,
 * and also from safe mode after a successful firmware upload.
 */
void resetBootCounter()
{
  Preferences prefs;
  prefs.begin(SAFE_MODE_NVS_NAMESPACE, false);
  prefs.putUInt(SAFE_MODE_NVS_KEY, 0);
  prefs.end();
}

/**
 * @brief Enters safe mode due to a detected boot loop.
 *
 * This function never returns. It initializes only the minimal set of
 * peripherals needed to allow firmware upload over WiFi:
 * - Display (for status messages)
 * - ConfigManager (read-only, for WiFi credentials)
 * - WiFi (STA with saved credentials, or AP fallback)
 * - A minimal web server with OTA upload capability
 *
 * It deliberately avoids initializing sensors, alarms, time management,
 * or the full web server to prevent re-triggering whatever crash caused
 * the boot loop.
 */
void enterSafeMode()
{
  auto &logger = SerialLog::getInstance();
  logger.print("\n*** ENTERING SAFE MODE ***\n");
  logger.print("Boot loop detected. Starting minimal recovery environment.\n");

  // Initialize display
  auto &display = Display::getInstance();
  display.begin();
  display.drawMultiLineStatusMessage("SAFE MODE", "Starting WiFi...");

  // Initialize ConfigManager to read saved WiFi credentials
  ConfigManager::getInstance().begin();

  // Attempt WiFi STA connection with saved credentials
  String ssid = ConfigManager::getInstance().getWifiSSID();
  String password = ConfigManager::getInstance().getWifiPassword();
  bool wifiConnected = false;
  DNSServer *dnsServer = nullptr;

  if (ssid.length() > 0)
  {
    logger.printf("Safe Mode: Attempting to connect to SSID: %s\n", ssid.c_str());
    display.drawMultiLineStatusMessage("SAFE MODE", "Connecting WiFi...");
    WiFi.mode(WIFI_STA);
    WiFi.begin(ssid.c_str(), password.c_str());

    unsigned long startTime = millis();
    while (WiFi.status() != WL_CONNECTED && millis() - startTime < SAFE_MODE_WIFI_TIMEOUT)
    {
      delay(250);
      logger.print(".");
      esp_task_wdt_reset();
    }

    if (WiFi.status() == WL_CONNECTED)
    {
      wifiConnected = true;
      logger.printf("\nSafe Mode: WiFi connected! IP: %s\n", WiFi.localIP().toString().c_str());
      display.drawMultiLineStatusMessage("SAFE MODE", ("IP: " + WiFi.localIP().toString()).c_str());
    }
    else
    {
      logger.print("\nSafe Mode: WiFi connection failed.\n");
      WiFi.disconnect(true);
    }
  }

  // If STA failed, start AP
  if (!wifiConnected)
  {
    logger.printf("Safe Mode: Starting AP '%s'\n", SAFE_MODE_AP_SSID);
    WiFi.mode(WIFI_AP);
    WiFi.softAP(SAFE_MODE_AP_SSID);
    IPAddress apIP = WiFi.softAPIP();
    logger.printf("Safe Mode: AP IP: %s\n", apIP.toString().c_str());
    display.drawMultiLineStatusMessage("SAFE MODE", ("AP: " + String(SAFE_MODE_AP_SSID)).c_str());

    // Start DNS server for captive portal behavior
    dnsServer = new DNSServer();
    dnsServer->setErrorReplyCode(DNSReplyCode::NoError);
    dnsServer->start(53, "*", apIP);
  }

  // Create a minimal web server (separate from ClockWebServer)
  AsyncWebServer safeServer(80);

  // Serve the safe mode HTML page
  safeServer.on("/", HTTP_GET, [](AsyncWebServerRequest *request)
                { request->send_P(200, "text/html", SAFE_MODE_HTML); });

  // Handle firmware upload (reuses UpdateManager)
  safeServer.on(
      "/update", HTTP_POST,
      [](AsyncWebServerRequest *request)
      {
        // Response is sent in the upload handler's final callback
      },
      [](AsyncWebServerRequest *request, String filename, size_t index,
         uint8_t *data, size_t len, bool final)
      {
        if (UpdateManager::getInstance().isUpdateInProgress() && index == 0)
        {
          request->send(409, "text/plain", "An update is already in progress.");
          return;
        }
        UpdateManager::getInstance().handleFileUpload(data, len, index, request->contentLength());
        if (final)
        {
          if (UpdateManager::getInstance().endUpdate())
          {
            // Reset boot counter so the new firmware boots normally
            resetBootCounter();
            request->onDisconnect([](){ SerialLog::getInstance().clearCrashLogMagic(); ESP.restart(); });
            request->send(200, "text/plain", "Update successful! Rebooting...");
          }
          else
          {
            String err = UpdateManager::getInstance().getLastError();
            request->send(500, "text/plain", "Update failed: " + (err.length() > 0 ? err : String("Unknown error.")));
          }
        }
      });

  // Reboot endpoint
  safeServer.on("/reboot", HTTP_GET, [](AsyncWebServerRequest *request)
                {
    request->send(200, "text/plain", "Rebooting...");
    request->onDisconnect([](){ SerialLog::getInstance().clearCrashLogMagic(); ESP.restart(); }); });

  // Catch-all for captive portal redirect (AP mode only)
  if (!wifiConnected)
  {
    safeServer.onNotFound([](AsyncWebServerRequest *request)
                          {
      String redirectUrl = "http://" + request->host();
      request->redirect(redirectUrl); });
  }

  safeServer.begin();
  logger.print("Safe Mode: Web server started. Waiting for firmware upload.\n");

  // Infinite loop — safe mode never exits except via reboot/reflash
  for (;;)
  {
    if (dnsServer)
    {
      dnsServer->processNextRequest();
    }
    esp_task_wdt_reset();
    delay(10);
  }
}

/**
 * @brief Triggers a factory reset, logs the source, and reboots the device.
 * @param source A string indicating what triggered the reset (e.g., "snooze button").
 * @param needsConfigInit A boolean indicating if the ConfigManager needs to be initialized.
 *                        This is true for boot-time resets.
 */
void triggerFactoryReset(const char *source, bool needsConfigInit)
{
  auto &logger = SerialLog::getInstance();
  logger.printf("Factory reset triggered by %s.\n", source);

  // Attempt to show a message on the display.
  Display::getInstance().drawStatusMessage("Resetting...");

  // For boot-time resets, the ConfigManager must be initialized first.
  if (needsConfigInit)
  {
    ConfigManager::getInstance().begin();
  }

  ConfigManager::getInstance().factoryReset();
  SerialLog::getInstance().clearCrashLogMagic();
  ESP.restart(); // The device will restart into a clean state.
}

/**
 * @brief Handles the boot button check for factory reset during runtime.
 */
void handleBootButton()
{
  if (digitalRead(BOOT_BUTTON_PIN) == LOW)
  {
    if (g_bootButtonPressTime == 0)
    {
      // Button was just pressed
      g_bootButtonPressTime = millis();
      SerialLog::getInstance().print("Boot button pressed. Timer started for factory reset...\n");
    }
    else if (millis() - g_bootButtonPressTime > FACTORY_RESET_HOLD_TIME)
    {
      // Button has been held for 10 seconds
      triggerFactoryReset("boot button", false);
    }
  }
  else
  {
    if (g_bootButtonPressTime > 0)
    {
      // Button was released before the 10-second mark
      SerialLog::getInstance().print("Boot button released. Factory reset cancelled.\n");
      g_bootButtonPressTime = 0;
    }
  }
}

/**
 * @brief The background logic task running on Core 0.
 *
 * Handles network connectivity, time synchronization, weather updates,
 * and configuration saving.
 */
void logicTask(void *pvParameters)
{
  SerialLog::getInstance().print("Logic Task started on Core 0\n");
  esp_task_wdt_add(NULL); // Add this task to the WDT

  auto &wifiManager = WiFiManager::getInstance();
  auto &timeManager = TimeManager::getInstance();
  auto &config = ConfigManager::getInstance();
  auto &weatherService = WeatherService::getInstance();

  for (;;)
  {
    if (!UpdateManager::getInstance().isUpdateInProgress())
    {
      if (!config.isOfflineMode())
      {
        // Handle WiFi
        wifiManager.handleDns();
        wifiManager.handleConnection();
        weatherService.loop();
      }

      config.loop();
    }

    if (!UpdateManager::getInstance().isUpdateInProgress() && wifiManager.isConnected())
    {
      timeManager.updateNtp();
      timeManager.checkDailySync();
      timeManager.checkDriftAndResync();
    }

    // Handle Serial Log (WebSocket updates etc)
    SerialLog::getInstance().loop();

    // Log heap every minute to track stability and fragmentation
    static unsigned long lastHeapLog = 0;
    if (millis() - lastHeapLog > 60000)
    {
      SerialLog::getInstance().printf(
          "Logic Task Heartbeat - Free: %u | Min: %u | MaxAlloc: %u\n",
          ESP.getFreeHeap(), ESP.getMinFreeHeap(), ESP.getMaxAllocHeap());
      lastHeapLog = millis();
    }

    // Periodically clean up stale WebSocket clients to prevent heap corruption
    static unsigned long lastWsCleanup = 0;
    if (millis() - lastWsCleanup > 1000)
    {
      SerialLog::getInstance().cleanupClients();
      lastWsCleanup = millis();
    }

    // Yield to prevent watchdog triggers
    vTaskDelay(pdMS_TO_TICKS(10));
    esp_task_wdt_reset(); // Feed the watchdog
  }
}
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
void loop()
{
  esp_task_wdt_reset(); // Feed the watchdog

  // Defer resetting the boot counter until the firmware has run stably for 30 seconds.
  static bool bootCounterResetDone = false;
  unsigned long currentMillis = millis();
  if (!bootCounterResetDone && currentMillis > 30000)
  {
    resetBootCounter();
    esp_ota_mark_app_valid_cancel_rollback(); // Confirm OTA update success to prevent rollback
    SerialLog::getInstance().print("Uptime reached 30s. Boot counter reset and OTA marked valid. Firmware is stable.\n");
    bootCounterResetDone = true;
  }

  // Implement a non-blocking delay to prevent watchdog timeouts and save CPU.
  // By delaying for the exact remaining time, we allow Core 1 to be fully utilized
  // by other tasks (like WeatherUpdate) without waking up this task every 1ms.
  unsigned long elapsed = currentMillis - g_lastLoopTime;
  if (elapsed < LOOP_INTERVAL)
  {
    vTaskDelay(pdMS_TO_TICKS(LOOP_INTERVAL - elapsed));
  }
  g_lastLoopTime = millis();

  // --- Core Clock Logic (Runs regardless of WiFi connection) ---
  auto &timeManager = TimeManager::getInstance();
  auto &display = Display::getInstance();
  auto &displayManager = DisplayManager::getInstance();
  auto &alarmManager = AlarmManager::getInstance();
  auto &config = ConfigManager::getInstance();

  // Perform periodic tasks that don't require WiFi.
  // Note: Config, Weather, WiFi, and SerialLog loops are now in Logic Task (Core 0)

  alarmManager.update();
  bool timeUpdated = timeManager.update(); // Updates time from the RTC
  if (g_alarm_triggered)
  {
    g_alarm_triggered = false;
    timeManager.handleAlarm();
  }
  timeManager.updateSnoozeStates();
  display.updateBrightness();
  handleSensorUpdates();

  // Update the current display page if the time has changed.
  if (timeUpdated)
  {
    displayManager.update();
  }

  // Check if settings have changed and need a reload.
  if (config.isDirty())
  {
    config.clearDirtyFlag();
    displayManager.refresh();
    timeManager.setNextAlarms();
    SerialLog::getInstance().print("Settings changed, refreshing display.\n");
    // Re-evaluate snooze state and update display
    timeManager.updateSnoozeStates();
    displayManager.update();
  }

  // --- Get alarm summary once per loop to avoid heap copies ---
  bool anyAlarmEnabled = false;
  bool anyAlarmSnoozed = false;
  config.getAlarmSummary(anyAlarmEnabled, anyAlarmSnoozed);

  // --- Alarm State Machine ---
  updateAlarmState(anyAlarmSnoozed);

  // State actions
  switch (g_alarmState)
  {
  case RINGING:
    // --- Polling-based logic for when an alarm is active ---
    if (digitalRead(SNOOZE_BUTTON_PIN) == LOW)
    {
      // Button is currently pressed
      if (s_alarmButtonPressTime == 0)
      {
        // Button was just pressed
        s_alarmButtonPressTime = currentMillis;
        s_actionTaken = false;
        SerialLog::getInstance().print("Alarm active: Button press detected.\n");
      }
      else if (!s_actionTaken)
      {
        // Update the progress bar while the button is held
        unsigned long dismissDurationMs = config.getDismissDuration() * 1000;
        float progress = (float)(currentMillis - s_alarmButtonPressTime) / dismissDurationMs;
        displayManager.setDismissProgress(progress);
        displayManager.update();
      }

      if (!s_actionTaken && currentMillis - s_alarmButtonPressTime > (config.getDismissDuration() * 1000))
      {
        // Button has been held long enough, dismiss the alarm
        SerialLog::getInstance().print("Alarm active: Button held. Dismissing.\n");
        int alarmId = alarmManager.getActiveAlarmId();
        if (alarmId != -1)
        {
          Alarm alarm = config.getAlarmById(alarmId);
          if (alarm.getId() != 255)
          {
            alarm.dismiss(timeManager.getCachedTime());
            config.setAlarmById(alarmId, alarm);
            config.scheduleSave();
          }
          alarmManager.stop();

          // Reset the progress bar to 0 and then force a full render update
          // to show the new snooze state and ensure the progress bar is cleared.
          displayManager.setDismissProgress(0.0f);
          displayManager.update();
        }
        s_actionTaken = true; // Ensure dismiss is only called once
      }
    }
    else
    {
      // Button is not pressed (it's released)
      if (s_alarmButtonPressTime > 0 && !s_actionTaken)
      {
        // Button was released before the dismiss action, so snooze.
        SerialLog::getInstance().print("Alarm active: Button released. Snoozing.\n");
        int alarmId = alarmManager.getActiveAlarmId();
        if (alarmId != -1)
        {
          Alarm alarm = config.getAlarmById(alarmId);
          if (alarm.getId() != 255)
          {
            alarm.snooze(config.getSnoozeDuration());
            config.setAlarmById(alarmId, alarm);
            config.scheduleSave();
          }
          alarmManager.stop();

          // Reset the progress bar and then force a full render update
          // to show the new snooze state and ensure the progress bar is cleared.
          displayManager.setDismissProgress(0.0f);
          displayManager.update();
        }
      }
      // Always reset the button timer and action flag on release.
      s_alarmButtonPressTime = 0;
      s_actionTaken = false;
      snoozeButton.clearNewPress();
    }
    break;

  case SNOOZED:
    // --- Polling-based logic for when an alarm is snoozed ---
    if (digitalRead(SNOOZE_BUTTON_PIN) == LOW)
    {
      // Button is currently pressed
      if (s_alarmButtonPressTime == 0)
      {
        // Button was just pressed
        s_alarmButtonPressTime = currentMillis;
        s_actionTaken = false;
        SerialLog::getInstance().print("Snooze active: Button press detected.\n");
      }
      else if (!s_actionTaken)
      {
        // Update the progress bar while the button is held
        unsigned long dismissDurationMs = config.getDismissDuration() * 1000;
        float progress = (float)(currentMillis - s_alarmButtonPressTime) / (float)dismissDurationMs;
        displayManager.setDismissProgress(progress);
        displayManager.update();
      }

      // If the button is held long enough, end the snooze for all snoozed alarms
      if (!s_actionTaken && currentMillis - s_alarmButtonPressTime > (config.getDismissDuration() * 1000))
      {
        SerialLog::getInstance().print("Snooze active: Button held. Ending snooze.\n");
        // Use a fresh copy here since we need to mutate and save
        std::vector<Alarm> snoozedAlarms = config.getAllAlarms();
        for (auto &alarm : snoozedAlarms)
        {
          if (alarm.isSnoozed())
          {
            alarm.dismiss(timeManager.getCachedTime());
            config.setAlarmById(alarm.getId(), alarm);
          }
        }
        config.scheduleSave();

        // Force the alarm sprite to re-render, which will now be empty
        displayManager.update();

        s_actionTaken = true; // Ensure action is only called once
        snoozeButton.clearNewPress();
      }
    }
    else
    {
      // Button is not pressed (it's released)
      if (s_alarmButtonPressTime > 0)
      {
        // If the button was being held, reset the progress bar and timer.
        displayManager.setDismissProgress(0.0f);
        displayManager.update();
        s_alarmButtonPressTime = 0;
        s_actionTaken = false;
        snoozeButton.clearNewPress();
      }
    }
    break;

  case IDLE:
    if (snoozeButton.newPressAvailable())
    {
      // --- Interrupt-based logic for normal operations (page cycling) ---
      unsigned long duration = snoozeButton.getPressDuration();
      snoozeButton.clearNewPress();

      SerialLog::getInstance().printf("Button press detected. Duration: %lu ms\n", duration);
      // A short press cycles pages.
      displayManager.cyclePage();
    }
    break;
  }

  // --- Update Alarm Icon ---
  displayManager.drawAlarmIcon(anyAlarmEnabled, anyAlarmSnoozed);

  handleBootButton();
}

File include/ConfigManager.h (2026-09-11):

// ConfigManager.h

#pragma once

#include <Arduino.h>
#include "Alarm.h"
#include <Preferences.h>
#include <vector>
#include <freertos/FreeRTOS.h>
#include <freertos/semphr.h>

const int LEGACY_ALARMS_COUNT = 5;  // Default number of alarms for legacy data migration
const int DEFAULT_ALARMS_COUNT = 2; // Default number of alarms for new installs/resets
const int MAX_ALLOWED_ALARMS = 20;  // Maximum number of alarms allowed

// Default Colors
static constexpr const char *DEFAULT_BACKGROUND_COLOR = "#000000";
static constexpr const char *DEFAULT_TIME_COLOR = "#079ae4";
static constexpr const char *DEFAULT_TOD_COLOR = "#FFFFFF";
static constexpr const char *DEFAULT_SECONDS_COLOR = "#02e3ab";
static constexpr const char *DEFAULT_DAY_OF_WEEK_COLOR = "#FFFFFF";
static constexpr const char *DEFAULT_DATE_COLOR = "#FFFFFF";
static constexpr const char *DEFAULT_TEMP_COLOR = "#02e3ab";
static constexpr const char *DEFAULT_HUMIDITY_COLOR = "#079ae4";
static constexpr const char *DEFAULT_ALARM_ICON_COLOR = "#FFFF00";
static constexpr const char *DEFAULT_SNOOZE_ICON_COLOR = "#0000FF";
static constexpr const char *DEFAULT_ALARM_TEXT_COLOR = "#FF0000";
static constexpr const char *DEFAULT_ERROR_TEXT_COLOR = "#FF0000";
static constexpr const char *DEFAULT_WEATHER_TEMP_COLOR = "#02e3ab";
static constexpr const char *DEFAULT_WEATHER_FORECAST_COLOR = "#FFFFFF";

// Default System Settings
static constexpr const char *DEFAULT_WIFI_SSID = "";
static constexpr const char *DEFAULT_WIFI_PASSWORD = "";
static constexpr const char *DEFAULT_HOSTNAME = "";
static constexpr bool DEFAULT_WIFI_CREDS_VALID = false;
static constexpr int8_t DEFAULT_RINGING_ALARM_ID = -1;
static constexpr uint32_t DEFAULT_RINGING_ALARM_TIMESTAMP = 0;
static constexpr bool DEFAULT_AUTO_BRIGHTNESS = true;
static constexpr uint8_t DEFAULT_BRIGHTNESS = 128;
static constexpr uint8_t DEFAULT_AUTO_BRIGHTNESS_START_HOUR = 7;
static constexpr uint8_t DEFAULT_AUTO_BRIGHTNESS_END_HOUR = 21;
static constexpr uint8_t DEFAULT_DAY_BRIGHTNESS = 255;
static constexpr uint8_t DEFAULT_NIGHT_BRIGHTNESS = 10;
static constexpr bool DEFAULT_USE_24_HOUR_FORMAT = false;
static constexpr bool DEFAULT_USE_CELSIUS = false;
static constexpr bool DEFAULT_SCREEN_FLIPPED = false;
static constexpr bool DEFAULT_INVERT_COLORS = false;
static constexpr const char *DEFAULT_TIMEZONE = "EST5EDT,M3.2.0/2:00,M11.1.0/2:00";
static constexpr bool DEFAULT_TIME_CORRECTION_ENABLED = true;
static constexpr bool DEFAULT_TEMP_CORRECTION_ENABLED = true;
static constexpr bool DEFAULT_AUTO_TEMP_CALIBRATION = true;
static constexpr float DEFAULT_TEMP_CORRECTION = 0.0;
static constexpr float DEFAULT_TEMP_COMPENSATION_FACTOR = 0.50;
static constexpr bool DEFAULT_IS_DST = false;
static constexpr uint8_t DEFAULT_SNOOZE_DURATION = 9;
static constexpr uint8_t DEFAULT_DISMISS_DURATION = 3;
static constexpr const char *DEFAULT_ADDRESS = "";
static constexpr int DEFAULT_DEFAULT_PAGE = 0;
static constexpr float DEFAULT_LAT = 0.0;
static constexpr float DEFAULT_LON = 0.0;
static constexpr bool DEFAULT_OFFLINE_MODE = false;
// 0: Clock, 1: Weather, 2: Info, 3: Weather+Clock
// Using a C-style array for default initializer which can be easily converted to vector
static constexpr int DEFAULT_ENABLED_PAGES[] = {0, 1, 3, 2};

/**
 * @class ConfigManager
 * @brief Manages the application's configuration settings using a singleton pattern.
 *
 * This class is responsible for loading, saving, and managing all
 * configuration settings for the clock. It uses the ESP32's Preferences library
 * for persistent storage in non-volatile flash memory.
 */
class ConfigManager
{
public:
  /**
   * @brief Gets the singleton instance of the ConfigManager.
   * @return A reference to the singleton ConfigManager instance.
   */
  static ConfigManager &getInstance()
  {
    static ConfigManager instance;
    return instance;
  }

  /**
   * @brief Initializes the configuration manager.
   *
   * Initializes NVS Preferences for persistent configuration storage.
   * Populates default values if settings have not yet been stored.
   * This should be called once at startup.
   */
  void begin();

  /**
   * @brief Handles periodic tasks for the ConfigManager, like debounced saves.
   *
   * This should be called in the main application loop. It checks if a save
   * operation is pending and executes it after a debounce delay.
   */
  void loop();

  /**
   * @brief Saves the current configuration to NVS Preferences.
   * @return True if the save was successful, false otherwise.
   */
  bool save();

  /**
   * @brief Schedules a save operation.
   *
   * This method sets a flag to save the configuration after a short delay.
   * This is used to prevent rapid, successive writes to NVS when
   * multiple settings are changed in quick succession.
   */
  void scheduleSave();

  // Getters
  /**
   * @brief Gets the stored WiFi SSID.
   * @return The WiFi SSID as a String.
   */
  String getWifiSSID() const;
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

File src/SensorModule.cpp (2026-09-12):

/**
 * @file SensorModule.cpp
 * @brief Implements sensor initialization and data handling.
 *
 * This file contains the implementation for setting up and reading data from
 * the BME280 environmental sensor, the DS3231 Real-Time Clock, and the
 * ESP32's internal temperature sensor. It uses a caching mechanism to avoid
 * reading the sensors too frequently.
 */

#include "SensorModule.h"
#include "HardwareBus.h"
#include "ConfigManager.h"
#include "SerialLog.h"
#include "TimeManager.h"
#include "LockGuard.h"
#include "driver/temp_sensor.h"
#include <math.h>
#include <Wire.h>
#include "Display.h"

// Instantiate the global sensor objects declared in the header.
Adafruit_BME280 BME;
RTC_Type RTC;

// Static variables to cache the latest sensor readings.
static float cached_bme_temp_c = 0.0;
static float cached_raw_bme_temp_c = 0.0;
static float cached_rtc_temp_c = 0.0;
static float cached_core_temp_c = 0.0;
static float cached_humidity = 0.0;
static float cached_offset_c = 0.0;
static bool bme280_found = false; // Track BME280 sensor status
static unsigned long lastBmeRetry = 0;
const unsigned long BME_RETRY_INTERVAL = 10000; // Retry every 10 seconds if not found
const uint8_t BME280_I2C_ADDRESS = 0x76;

// EMA (Exponential Moving Average) state for smoothing the thermal delta.
static float smoothed_heat_delta = 0.0;
static bool ema_initialized = false;
const float EMA_ALPHA = 0.02; // Smoothing factor: lower = smoother, slower convergence (0.02 = ~15 min thermal inertia)

// EMA state for filtering BME280 raw sensor noise
static float smoothed_raw_bme_temp_c = 0.0;
static float smoothed_raw_humidity = 0.0;
static bool bme_ema_initialized = false;
const float BME_EMA_ALPHA = 0.2; // Fast smoothing for signal noise

static bool rtc_found = false;        // Track RTC status
static bool core_temp_started = false; // Track whether temp_sensor_start() was called

// Auto-Calibration State
static bool auto_cal_running = false;
static unsigned long auto_cal_start_time = 0;
static float auto_cal_baseline_temp = 0.0;
static bool first_run_check_done = false;

/// @brief Stores the timestamp of the last sensor update for interval timing.
static unsigned long prevSensorMillis = 0;

/**
 * @brief Initializes all hardware sensors.
 *
 * This function attempts to initialize the BME280 sensor and the RTC.
 * It also sets up the ESP32's internal temperature sensor. It then performs
 * an initial sensor read to populate the cached values.
 */
void setupSensors()
{
  // 9-clock SCL pulse recovery in GPIO mode before Wire.begin
  // If an unexpected reset occurred while a slave held SDA low,
  // clocking SCL up to 9 times frees the slave and recovers the bus.
  pinMode(I2C_SDA, INPUT_PULLUP);
  pinMode(I2C_SCL, OUTPUT_OPEN_DRAIN);
  digitalWrite(I2C_SCL, HIGH);
  delayMicroseconds(10);

  for (int i = 0; i < 9; ++i)
  {
    if (digitalRead(I2C_SDA) == HIGH)
    {
      break; // Slave released SDA
    }
    digitalWrite(I2C_SCL, LOW);
    delayMicroseconds(5);
    digitalWrite(I2C_SCL, HIGH);
    delayMicroseconds(5);
  }

  // Generate STOP condition: pull SCL LOW, set SDA LOW, release SCL HIGH, then release SDA HIGH
  digitalWrite(I2C_SCL, LOW);
  delayMicroseconds(5);
  pinMode(I2C_SDA, OUTPUT_OPEN_DRAIN);
  digitalWrite(I2C_SDA, LOW);
  delayMicroseconds(5);
  digitalWrite(I2C_SCL, HIGH);
  delayMicroseconds(5);
  digitalWrite(I2C_SDA, HIGH);
  delayMicroseconds(5);

  pinMode(I2C_SDA, INPUT);
  pinMode(I2C_SCL, INPUT);

  Wire.begin(I2C_SDA, I2C_SCL, 100000);
  Wire.setTimeOut(50); // 50ms timeout to prevent indefinite bus hangs

  for (int i = 0; i < SENSOR_RETRY_COUNT; ++i)
  {
    bme280_found = BME.begin(BME280_I2C_ADDRESS);
    if (bme280_found)
      break;
    delay(SENSOR_RETRY_DELAY);
  }

  if (!bme280_found)
  {
    SerialLog::getInstance().print("Could not find a valid BME280 sensor, check wiring!");
    // The device will now rely on the RTC for temperature.
  }

  for (int i = 0; i < SENSOR_RETRY_COUNT; ++i)
  {
    rtc_found = RTC.begin();
    if (rtc_found)
      break;
    delay(SENSOR_RETRY_DELAY);
  }

  if (!rtc_found)
  {
    SerialLog::getInstance().print("Couldn't find RTC");
    // The main loop will now handle the error message.
    return; // Exit early, no point in continuing
  }

  // Initialize the internal temperature sensor
  temp_sensor_config_t temp_sensor = TSENS_CONFIG_DEFAULT();
  temp_sensor_set_config(temp_sensor);
  temp_sensor_start();
  core_temp_started = true;

  // Perform an initial sensor read to populate cached values.
  handleSensorUpdates(true);
}

/**
 * @brief Checks if the RTC module was found.
 * @return True if the RTC is available, false otherwise.
 */
bool isRtcFound()
{
  return rtc_found;
}

/**
 * @brief Checks if the BME280 sensor was found.
 * @return True if the BME280 is available, false otherwise.
 */
bool isBmeFound()
{
  return bme280_found;
}

/**
 * @brief Gets the primary temperature reading.
 *
 * Returns the BME280 temperature if available, otherwise falls back to the
 * RTC temperature. The value is converted to the user's preferred unit (C/F).
 *
 * @return The current temperature.
 */
float getTemperature()
{
  if (bme280_found)
  {
    return getBmeTemperature();
  }
  else
  {
    return getRtcTemperature();
  }
}

/**
 * @brief Gets the last cached humidity reading.
 * @return The relative humidity, or -1 if the BME280 is not available.
 */
float getHumidity()
{
  return cached_humidity;
}

/**
 * @brief Gets the BME280 temperature, converted to the user's preferred unit.
 * @return The BME280 temperature.
 */
float getBmeTemperature()
{
  bool useCelsius = ConfigManager::getInstance().isCelsius();
  if (useCelsius)
  {
    return cached_bme_temp_c;
  }
  else
  {
    return celsiusToFahrenheit(cached_bme_temp_c);
  }
}

/**
 * @brief Gets the RTC's internal temperature, converted to the user's preferred unit.
 * @return The RTC temperature.
 */
float getRtcTemperature()
{
  bool useCelsius = ConfigManager::getInstance().isCelsius();
  if (useCelsius)
  {
    return cached_rtc_temp_c;
  }
  else
  {
    return celsiusToFahrenheit(cached_rtc_temp_c);
  }
}

/**
 * @brief Gets the ESP32's internal core temperature, converted to the user's preferred unit.
 * @return The core temperature.
 */
float getCoreTemperature()
{
  bool useCelsius = ConfigManager::getInstance().isCelsius();
  if (useCelsius)
  {
    return cached_core_temp_c;
  }
  else
  {
    return celsiusToFahrenheit(cached_core_temp_c);
  }
}
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

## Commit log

2025-10-02 Add project template
    [default_16MB.csv]
2025-10-03 Update sensors for Wokwi
2025-10-04 Update partitions
    [default_16MB.csv, partitions.csv]
2025-10-10 Add reboot button to settings
2025-10-10 WIP: Add display ,manager to allow switching between pages. Includes sensors and display refactor
2025-10-10 Add dirty flag to track settings changes and force display update
2025-10-10 Fix memory leak in `main.cpp` by using `std::unique_ptr` to manage the lifecycle of the `ClockPage` object
    [main.cpp]
2025-10-10 Remove MISO pin
2025-10-11 Improve alarm reliability by checking missed minutes
    [TimeManager.cpp]
2025-10-15 Update pins and partitions
    [partitions.csv]
2025-10-16 Refactor alarm buzzer and add ramping alarm
    [AlarmManager.cpp]
2025-10-17 Update sensors more frequently
2025-10-17 feat: Add degree symbol to temperature display
2025-10-17 feat: Add more debug serial printing
2025-10-18 fix: Disable WiFi power-saving to improve mDNS stability
2025-10-18 Switch ntp to new logger
2025-10-18 Fix NTP log spam after daily sync
    [TimeManager.cpp]
2025-10-18 Disable buttons during update/update check
2025-10-18 Fix: Correct snooze logic
    [ConfigManager.h, TimeManager.cpp]
2025-10-18 SerialLog print -> println
2025-10-18 Factory reset if boot button is pressed for 1 min
    [ConfigManager.h, main.cpp]
2025-10-19 ESP32-Clock-Setup -> Clock-Setup
2025-10-20 Increase main Main SPI frequency to 75MHz
2025-10-20 feat: Add factory reset button to web UI
2025-10-20 Fix: Manually control alarm settings collapse to prevent mis-toggle
    [web_content.h]
2025-10-20 feat: Prevent AP mode on WiFi outage with valid credentials
    [ConfigManager.h]
2025-10-20 fix: Prevent daily time sync loop when offline
    [TimeManager.cpp, main.cpp]
2025-10-20 fix(ConfigManager): Add mutex to prevent race condition in save()
    [ConfigManager.h]
2025-10-21 fix: Resolve race condition in manual WiFi scan
    [web_content.h]
2025-10-21 feat: Implement DS3231 temperature fallback
2025-10-21 fix: Add visual alert for RTC initialization failure
    [main.cpp]
2025-10-21 Refactor: Improve ClockPage layout and temperature display
2025-10-22 Fix: Resolve online update errors
    [web_content.h]
2025-10-22 fix(captive-portal): Increase input font size to prevent iOS zoom
    [web_content.h]
2025-10-22 change factory reset to 30 seconds
    [main.cpp]
2025-10-22 feat: Create separate reset buttons for general and display settings
2025-10-22 Don't track version number changes
2025-10-22 Fix alarm panel not being the correct width
    [web_content.h]
2025-10-23 feat: Add autosave countdown timer to settings and alarms pages
2025-10-23 feat: Use snooze button for boot-time factory reset
    [main.cpp]
2025-10-25 feat: Add live sensor data updates to web UI
2025-10-25 feat: Implement factory reset that keeps wifi credentials
    [ConfigManager.h, web_content.h]
2025-10-25 feat: Add ESP32-S3 core temperature API and display
2025-10-25 feat: Disable factory reset during firmware updates
    [web_content.h]
2025-10-26 fix: Clear pending button press on alarm activation
    [main.cpp]
2025-10-26 feat: Add NTP sync button to web ui
2025-10-28 feat: Implement periodic clock drift check and resync
    [TimeManager.cpp, main.cpp]
2025-10-28 Revert: Use non-blocking NTP sync on startup if RTC is set
    [TimeManager.cpp]
2025-10-28 feat: Allow holding snooze button to end snooze
2025-10-29 feat: Refactor alarm system to use RTC hardware interrupts
2025-10-29 Refactor: Switch from Littlefs JSON to Preferences
2025-10-29 Fix: Shortened preference keys to be within the 15-character limit of the NVS driver
2025-10-29 Fix: Implement RTC alarm look-back on boot
    [TimeManager.cpp]
2025-10-29 fix: Preserve snooze state during settings reset
    [ConfigManager.h]
2025-10-30 Refactor ButtonManager to be instance-safe and improve button handling
2025-10-31 feat: Add option to invert display colors
    [ConfigManager.h, Display.cpp, WebContent.h]
2025-10-31 fix(websocket): Correct WebSocket endpoint to /ws/log
    [WebContent.h]
2025-10-31 fix: Apply display settings on boot and add comprehensive mutex locking to prevent crash
    [Display.cpp, main.cpp]
2025-11-01 fix: Add retry logic to sensor initialization
    [SensorModule.cpp, SensorModule.h, main.cpp]
2025-11-01 docs: Add coming soon for 3D models and assembly
2025-11-02 Fix: Disable 'Sync now' button during software updates
    [WebContent.h]
2025-11-02 fix: Correct DST transition and update sync time
    [ConfigManager.h, TimeManager.cpp, WebContent.h]
2025-11-02 Fix(SerialLog): Prevent WebSocket crash on Safari by removing initial ping
    [SerialLog.cpp]
2025-11-02 fix(settings): Populate timezone dropdown on page load
    [WebContent.h]
2025-11-03 feat: Add temperature offset and humidity correction
    [ConfigManager.h, SensorModule.cpp, WebContent.h]
2025-11-15 Add parts list, assembly instructions, and case model to README
    [ESP32 Clock Case 4 inch v18.step]
2025-11-27 Remove old software polling alarm system in favor of hardware interrupt system
2025-11-27 Ensure display updates immediately after NTP sync or drift correction
    [TimeManager.cpp, main.cpp]
2025-11-28 Fix BME280 sensor recovery
    [SensorModule.cpp]
2025-11-29 Add thread-safe log rollover functionality and Web UI button
2025-11-30 Fix missing weather unit and switch weather provider to Open-Meteo
    [WeatherService.h]
2025-11-30 Add WeatherClockPage combining clock and alternating weather/indoor sensors
2025-11-30 Refactor alarm overlay to be global and prevent page switching on alarm trigger
    [AlarmManager.cpp, main.cpp]
2025-11-30 Add feels like, humidity, wind, and pressure to weather page of web ui
2025-11-30 Add feels like, humidity, wind, and pressure to weather page
2025-12-01 Fix ConfigManager deadlocks, SerialLog/WiFiManager/WeatherService race conditions, and clean up headers.
    [SerialLog.cpp, WeatherService.h]
2025-12-02 Replace Zip Code with location for Weather
    [ConfigManager.h, WeatherService.h, WebContent.h]
2025-12-02 Enable aggressive logging and watchdog configuration for crash diagnostics
    [SerialLog.cpp, main.cpp]
2025-12-02 feat: Replace pressure with rain chance on weather page
    [WeatherService.h, WebContent.h]
2025-12-03 improve thread safety in AlarmManager and WeatherService
2025-12-05 Fix race condition in alarm iteration by adding `getAllAlarms()`
    [ConfigManager.h, TimeManager.cpp, main.cpp]
2025-12-06 Style the "Feels Like" temperature unit on WeatherPage
2025-12-13 Fix seconds counter drift and sticking issues.
    [TimeManager.cpp]
2025-12-16 Fix stored XSS in hostname configuration
    [WebContent.h]
2025-12-16 Fix: append `.local` to the displayed hostname
    [WebContent.h]
2025-12-24 Add crash indicator for dev builds
    [main.cpp]
2026-02-15 Fixed a potential memory leak where interrupted uploads would leave data in the heap
    [main.cpp]
2026-03-01 FIX: Have setTimezone() update the TZ environment variable
    [TimeManager.cpp]
2026-03-01 Optimize heap fragmentation and fix thread safety
    - Convert WeatherService from 10m spawn/destroy to persistent task
    - Fix WeatherService WDT crash (scoping to HTTP work only)
    - Add NTP state machine mutex and safe logicTask stack size
    - Prevent async loop block with delay() to onDisconnect() swap
    - Buffer TimeManager display getters to char[] instead of String
    - Refactor ClockPage/WeatherClockPage to use char[] for display data
    - Extract ClockDisplayBase to unify render/update loops
    - Replace Vector copies in alarm Snooze with getFirstSnoozedUntil()
    - Use ps_malloc for OTA firmware HTTP buffer
    - Use snprintf for ConfigManager alarm iteration (removes String keys)
    [ConfigManager.h, SerialLog.cpp]
2026-05-24 Add better crash logging, time sync, and thread handling
    [SerialLog.cpp, TimeManager.cpp, WebContent.h]
2026-06-14 Improve crash resistance in weather service
2026-06-19 Add cold boot auto temp calibration
2026-06-20 Add auto calibration for temp on cold boot
2026-06-20 Fix updates logging as crashes
    [SerialLog.cpp, main.cpp]
2026-07-25 Improve weather service and little fs crash resistance plus other improvements
    [AlarmManager.cpp, ButtonManager.cpp]
2026-08-23 Add OTA confirmation to prevent rollback after 30s uptime
    [main.cpp]
2026-08-27 Refactor weather data structures to use fixed-size character arrays for conditions, sunrise, and sunset; update related logic for consistency and performance improvements.
    [WeatherService.h, main.cpp]
2026-08-27 Enhance SerialLog loop for improved buffer management and prevent heap growth; adjust flushing logic to handle log buffer thresholds safely.
    [SerialLog.cpp]
2026-09-07 Refactor SerialLog file handling to improve robustness; replace "a" mode with "r+" for log file operations, enhance crash log handling, and optimize critical section management to prevent potential i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
    [SerialLog.cpp]
2026-09-11 Fix web UX issues and update documentation
    [AlarmManager.cpp, ButtonManager.cpp, ConfigManager.h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]
2026-09-12 Add unit tests for various components
    - Implement tests for LockGuard and RecursiveLockGuard in test_lock_guard.cpp to verify behavior with null mutex and RAII acquisition/release.
    - Create tests for NTP synchronization in test_ntp_sync.cpp, including initial state and start/reset functionality.
    - Add comprehensive unit tests for OTA scripts in test_ota_scripts.py, covering key generation, firmware signing, and version formatting.
    - Re-export OTA script tests in test_scripts/test_ota_scripts.py for easier access.
    - Introduce tests for firmware version checks in test_scripts/test_scripts.cpp to ensure version definition and format.
    - Implement sensor module tests in test_sensor.cpp, focusing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
    [SensorModule.cpp, SensorModule.h, TimeManager.cpp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]
2026-11-01 Enhance time management by adding mutex protection for timezone changes and missed alarm checks; update checkMissedAlarmsWindow to handle skipped hours, and ensure thread safety in time-related funct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
